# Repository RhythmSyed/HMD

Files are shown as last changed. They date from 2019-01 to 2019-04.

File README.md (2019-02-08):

# HMD
ECE 477 Team 6

HMD is a wearable Health Monitoring Device that provides the user with real-time health information through a continuous stream to the cloud and to a companion app for client-side use. The system includes a wide variety of sensors that allow the device to monitor the activity of the user through step tracking and monitoring sleep quality. To ensure uninterrupted wear, the battery level of the device is recorded to insure the device is always powered. The system also includes an alert system for sleep reminders, low battery levels, and alerts to family members in case of health concerns. The system will also incorporate a display attached to the wearable informing the user his total steps and the battery percentage of the device.

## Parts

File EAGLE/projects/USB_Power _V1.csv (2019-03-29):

Qty | Value | Device | Package | Parts | Description | BOM
2 |  | HEADER-1X2ROUND | 1X02_ROUND | JP1, JP2 | PIN HEADER
1 |  | SOLDERJUMPER | SOLDERJUMPER_ARROW_NOPASTE | SJ1 | SMD Solder JUMPER | EXCLUDE
1 |  | USB_MEDIUM | USB-MINI_MEDIUM | X1 | USB Connectors
1 | 10K\ | RESISTOR0805_NOOUTLINE | 0805-NO | R3 | Resistors
2 | 10µF | CAP_CERAMIC0805-NOOUTLINE | 0805-NO | C1, C2 | Ceramic Capacitors
1 | 2.5K | RESISTOR0805_NOOUTLINE | 0805-NO | R4 | Resistors
1 | JSTPH | JST_2PIN | JSTPH2 | CN2 | JST 2-Pin Right-Angle Connector
1 | MCP73831T-2ACI/OT | MCP73831/2 | SOT23-5 | U1 | MCP73831/2 LIPO Charger

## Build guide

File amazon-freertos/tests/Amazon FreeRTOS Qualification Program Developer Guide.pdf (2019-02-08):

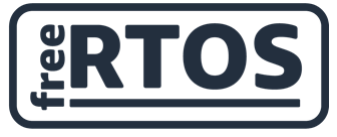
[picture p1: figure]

Copyright © 2018 Amazon Web Services, Inc. and/or its affiliates. All rights reserved.

# Amazon FreeRTOS Qualification Developer Guide

Document Version V1.1.3

Amazon FreeRTOS Qualification Developer Guide – V 1.1.3

Copyright © 2018 Amazon Web Services, Inc. and/or its affiliates. All rights reserved. | 2

## Amazon FreeRTOS Qualification: Developer Guide

Copyright © 2018 Amazon Web Services, Inc. and/or its affiliates. All rights reserved.

Amazon's trademarks and trade dress may not be used in connection with any product or service that is not Amazon's, in any manner that is likely to cause confusion among customers, or in any manner that disparages or discredits Amazon. All other trademarks not owned by Amazon are the property of their respective owners, who may or may not be affiliated with, connected to, or sponsored by Amazon.

Copyright © 2018 Amazon Web Services, Inc. and/or its affiliates. All rights reserved. | 3

# Revision History

Date | Versi on | Change History | Compatible Amazon FreeRTOS Version
July 31, 2018 | 1.0.0 | Initial Version. | 1.3.0
August 09, 2018 | 1.0.1 | Updates in appendices: • Updates in Porting Order chart. • Updates in PKCS#11 “Porting” section. • File path changes in TLS “Test Setup” section and TLS Server Setup step 9. • Fix hyperlinks in MQTT prerequisite section. • Add AWS CLI config instruction in BYOC certificate creation example. | 1.3.1 1.3.2
August 27, 2018 | 1.1.0 | Added tests for Over-the-air (OTA) updates and guidelines for bootloader | 1.4.0 1.4.1
October 08, 2018 | 1.1.1 | Added clarifications in (B3.1) tests enable constants table. Updated path changes of Unity module in “Create Test Project (B2.2)” section. Updates in appendices: • Updated Porting Order Flowchart. • Updated client credential certificate/key variable names in TLS “Test Setup” section. • Corrections of a file path in Secure Socket “Test Setup” section and TLS Server Setup. • Updated the path for echo servers in TLS “Test Setup” section and TLS Server Setup. | 1.4.2
November 07, 2018 | 1.1.2 | Updates in appendices: • Modifications of PKCS #11 PAL layer interface changes in PKCS #11 porting section. • Updated GSG template, “Download and Configure Amazon FreeRTOS” section. • Updated the path of CertificateConfigurator.html. | 1.4.3 1.4.4
November 26, 2018 | 1.1.3 | Added BLE section. Updated with IoT Device Tester information. Added cmake preparation section. | To be assigned

Copyright © 2018 Amazon Web Services, Inc. and/or its affiliates. All rights reserved. | 4

# Contents

Copyright © 2018 Amazon Web Services, Inc. and/or its affiliates. All rights reserved. | 5
5.15 | Appendix O: Checklist for Qualification | 67
5.16 | Appendix P: Troubleshooting Porting Setup | 68
5.17 | Appendix Q: Instructions to Create a BYOC (ECDSA) | 69
5.18 | Appendix R: Source for ca.config | 71
5.19 | Appendix S: Modify issuer in a certificate | 77
5.20 | Appendix T: Getting Started Guide Template | 81
5.21 | Appendix U: Hardware Information | 83
5.22 | Appendix V: Information for listing on the Amazon FreeRTOS Console | 85
5.23 | Appendix W: Glossary | 86

Copyright © 2018 Amazon Web Services, Inc. and/or its affiliates. All rights reserved. | 6

# 1 Introduction

## 1.1 What is the Amazon FreeRTOS Qualification?

The Amazon FreeRTOS Qualification (AFQ) defines a process that the author of an Amazon FreeRTOS port¹ must follow, and a set of tests that the port must pass, in order for the port to be described as 'qualified by Amazon'. Amazon only distributes and supports Amazon FreeRTOS ports that have passed the qualification program. The purpose of the AFQ is to give developers confidence that qualified Amazon FreeRTOS ports behave correctly and consistently with each other.

AWS provides a free test automation framework called AWS IoT Device Tester for Amazon FreeRTOS, which developers can use to automate running of the qualification tests. See https://aws.amazon.com/freertos/device-tester for more information on how to set it up.

## 1.2 Target System Requirements

It is recommended that Amazon FreeRTOS is only qualified on microcontrollers (MCUs) that have a minimum processing speed of 25MHz, a minimum of 64K bytes of RAM, and a minimum of 128K bytes of program memory per executable image stored on the MCU. For future qualification requirement with Over-the-air update (OTA) functionality, two executable images must be stored in program memory at the same time.

## 1.3 Document Outline

This document guides you through setting up your Amazon FreeRTOS project, porting Amazon FreeRTOS libraries, building and testing your ports using the Amazon FreeRTOS Qualification tests. Appendixes provide more detail information on each Amazon FreeRTOS library.

We also prepared a checklist for the process: Appendix O: Checklist for Qualification

1 An Amazon FreeRTOS port is a board-specific implementation of APIs for certain Amazon FreeRTOS libraries. The port enables these APIs to work on the specific board, and implements the required integration with device drivers and BSPs provided by the platform vendor. It should also include any configuration adjustments (e.g. clock rate, stack size, heap size etc.) required by the board.

Copyright © 2018 Amazon Web Services, Inc. and/or its affiliates. All rights reserved. | 7

# 2 Amazon FreeRTOS Qualification Test Project

Follow the steps below.

## 2.1 Download Amazon FreeRTOS Source Code

You can download the Amazon FreeRTOS source code and test code from GitHub:

https://github.com/aws/amazon-freertos

Please download the latest release code from the “release” branch. You should import the repository to your own private GitHub repository and configure to watch Amazon FreeRTOS public repository. You will get notifications if there are new releases on our release branch.

If you are using Windows, you must keep the file path short (for example clone to C:\AFreeRTOS rather than C:\Users\username\programs\projects\AmazonFreeRTOS\) to avoid a Windows limitation with long file paths. The chosen folder will be referred as $AFR_HOME from here on in the document.

## 2.2 Set Up Your Amazon FreeRTOS Project

At the end of this step, you will have a working project that can write to a serial console.

### 2.2.1 Preparing Amazon FreeRTOS Folders

All qualified Amazon FreeRTOS ports use the same directory structure. New files, including IDE project files, must be created in the correct folder locations.

The directory structure is explained below. Detailed instructions on how to create the same directory structure are listed in the grey box.

Directory Structure:

The three root level folders under $AFR_HOME are:

$AFR_HOME
├───demos | Contains projects that build demo applications
├───lib | Contains Amazon FreeRTOS and third-party libraries
└───tests | Contains projects that build qualification tests

Create your project in the tests folder, which is structured as follows:

$AFR_HOME
└───tests
├───common | Contains files built by all test projects
├───pc | Contains a reference test project for the FreeRTOS Windows port
└───vendor | Template, to be renamed to the name of the MCU vendor
└───board | Template, to be renamed to the name of the development board

Copyright © 2018 Amazon Web Services, Inc. and/or its affiliates. All rights reserved. | 8

Instructions:

1. Rename the $AFR_HOME/tests/vendor folder to the name of the company that manufactures the MCU – from here on the folder is referred to as [vendor].
2. Rename the $AFR_HOME/tests/board folder to the name of the development board being qualified – from here on the folder is referred to as [board].

The $AFR_HOME/tests/[vendor]/[board] folder is a template provided to simplify the creation of a new test project and ensures all test projects have a consistent organization. It has the following structure:

$AFR_HOME
└───tests
└───[vendor]
└───[board]
├───common
│ | ├───application_code | Contains main.c, which itself contains main()
│ | │ | └───vendor_code | Contains vendor supplied board specific files
│ | └───config_files | Contains Amazon FreeRTOS config files
└───ide | Contains an IDE specific project

Test projects always require vendor-supplied driver libraries. Some vendor-supplied libraries, such as a header file that maps a GPIO output to an LED output, are specific to the target development board. Other vendor-supplied libraries, such as the GPIO library itself, are specific to the target MCU family.

For Vendor-supplied driver libraries that are specific to the target development board:

Instructions (continued):

3. Save any required vendor-supplied libraries that are specific to the board in the $AFR_HOME/tests/[vendor]/[board]/common/application_code/vendor_code folder.
4. Rename the $AFR_HOME/tests/[vendor]/[board]/ide folder to the name of the IDE that will be used to build the test project – from here on the folder is referenced as [IDE].

Vendor-supplied driver libraries that are specific to the target MCU family belong in the $AFR_HOME/lib/third_party/mcu_vendor folder, which has the following structure:

$AFR_HOME
└─lib
├──AmazonLib1 | Contains an Amazon FreeRTOS library (example name only)
├──AmazonLib2 | Contains an Amazon FreeRTOS library (example name only)
└──third_party | Contains all non-board specific third-party libraries
├───Lib1 | Contains a third-party library (example name only)
├───Lib2 | Contains a third-party library (example name only)
└───mcu_vendor Contains vendor-supplied MCU specific libraries └──vendor Template, to be renamed to the name of the MCU vendor └─driver_library Template, to be renamed to the library name └─driver_library_version Template, to be renamed to the library version

Copyright © 2018 Amazon Web Services, Inc. and/or its affiliates. All rights reserved. | 9

Instructions (continued):

5. Rename the $AFR_HOME/lib/third_party/mcu_vendor/vendor folder to [vendor] (the name of the company that manufactures the MCU).
6. Likewise, rename the contained driver_library folder to the name of the vendor’s MCU specific driver library, and the contained driver_library_version folder to the version number of the vendor’s MCU specific driver library.
7. Copy the vendor-supplied driver library into the newly renamed driver_library_version folder.

NOTE: DO NOT save vendor-supplied libraries that are specific to the MCU family anywhere within either the $AFR_HOME/tests or $AFR_HOME/demos folders!

### 2.2.2 Create the Test Project

All qualified Amazon FreeRTOS test projects look the same when viewed from within an IDE. This section describes and demonstrates the required project structure. By the end of this section you will have a project with FreeRTOS Kernel libraries ready to run. The next section (2.32.3) will cover porting of other Amazon FreeRTOS libraries into the project.

Instructions:

1. Read this section of the document, and then replicate the project it describes, but using the selected IDE, and targeting the hardware being qualified. Take care to ensure the structure of the created project matches that described below.

NOTE 1: All files in the project must be built in the file’s original position within the folder structure. They are imported into the project by linking the files. Never directly copy files into the project’s folder or use absolute file paths.

NOTE 2: If you are using an Eclipse based IDE, do not configure the project to build all the files in any given folder. Instead, add source files into the project by linking to each source file individually.

The project is called aws_tests. Under aws_tests, there are three virtual folders. In this context, a virtual folder is created in an IDE to better organize the source code. It may not correspond to a physical directory on disk. The three virtual folders are application_code, config_files and lib, as described below:

aws_tests | The project name
├───application_code | Contains application logic, in this case it is AFQ test code
├───config_files | Contains header files that configure Amazon FreeRTOS libraries
└───lib | Contains Amazon and third-party libraries

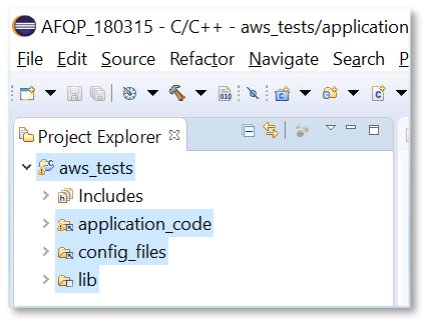
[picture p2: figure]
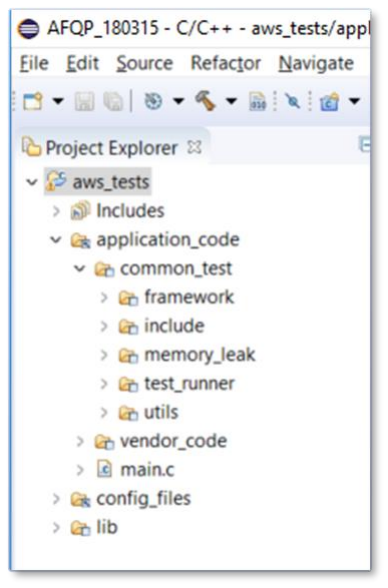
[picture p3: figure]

Copyright © 2018 Amazon Web Services, Inc. and/or its affiliates. All rights reserved. | 10

Error! Reference source not found. shows how the top three virtual folders appear in an IDE. The depicted IDE is Eclipse, but the structure is the same in all IDEs.

Figure 1 The top three virtual folders viewed in an IDE’s project explorer view

Figure 2 shows the contents of the application_code virtual folder.

Figure 2 An IDE project with the application_code virtual folder expanded

NOTE:

- The main.c file, and the vendor_code folder, are (physically on the disk) located in the $AFR_HOME/tests/[vendor]/[board]/common/ application_code folder.
- common_test is a virtual folder – it does not actually exist within the $AFR_HOME directory structure. The folders under common_test are located in the $AFR_HOME/tests/common folder. The project builds the source files located in those folders.

NOTE:

- The “Includes” folder is generated automatically by Eclipse. It is not part of the required structure

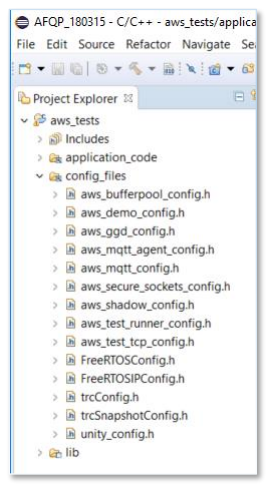
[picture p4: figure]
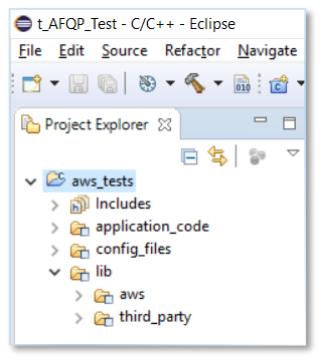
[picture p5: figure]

Copyright © 2018 Amazon Web Services, Inc. and/or its affiliates. All rights reserved. | 11

Figure 3 shows the contents of the config_files virtual folder.

Figure 3 An IDE project with the config_files folder expanded

Figure 4 shows the contents of the lib virtual folder.

Figure 4 IDE project with the lib group expanded

NOTE:

- The files shown under config_files are located in the
$AFR_HOME/tests/[vendor]/[board]/common /config_files folder.

NOTE:

- aws and third_party are virtual folders.

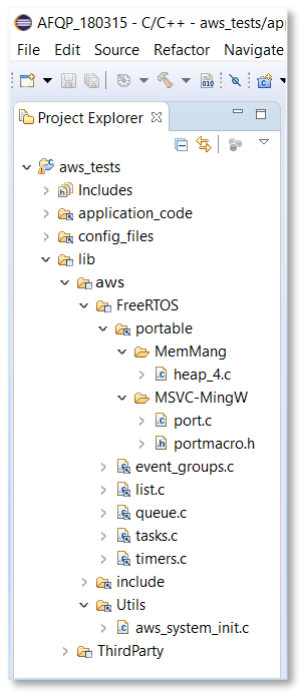
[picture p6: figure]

Copyright © 2018 Amazon Web Services, Inc. and/or its affiliates. All rights reserved. | 12

Figure 5 shows the contents of the lib/aws folder, which contains AWS (as opposed to third party) provided libraries. It only contains FreeRTOS kernel library at this stage. You will import more libraries in this folder during later porting effort.

Figure 5 IDE project with the lib/AWS group expanded

NOTE:

- The files and folders shown under lib/aws/FreeRTOS are located in the $AFR_HOME/lib/FreeRTOS folder. The figure shows lib/aws/FreeRTOS/portable/MSVC-MingW being included in the project. That folder contains the FreeRTOS kernel Windows port and should be substituted with whichever folder contains the correct FreeRTOS port for your target IDE and MCU, see below instruction.
- The file shown under
lib/aws/FreeRTOS/portable/MemMang is located in the $AFR_HOME/lib/FreeRTOS/MemMang folder. It is FreeRTOS memory management implementation.
- The files shown under lib/aws/include are located in the $AFR_HOME/lib/include folder. Although not shown in Figure , it includes all the header files and folders under $AFR_HOME/lib/include.
- aws_system_init.c is located in the $AFR_HOME/lib/utils folder.

Instructions (continued):

1. Replicate the folder structure (continued)
a. Import the FreeRTOS Kernel port for your compiler and architecture in place of lib/aws/FreeRTOS/portable/MSVC_MingW in Figure 5. $AFR_HOME/lib/FreeRTOS/portable contains the FreeRTOS kernel port files organized first by compiler, and then by architecture.
b. Import one of the FreeRTOS Kernel memory management implementation to lib/aws/FreeRTOS/portable/MemMang. For Amazon FreeRTOS, we use heap_4.c. For more information, please visit FreeRTOS Memory Management (https://www.freertos.org/a00111.html)

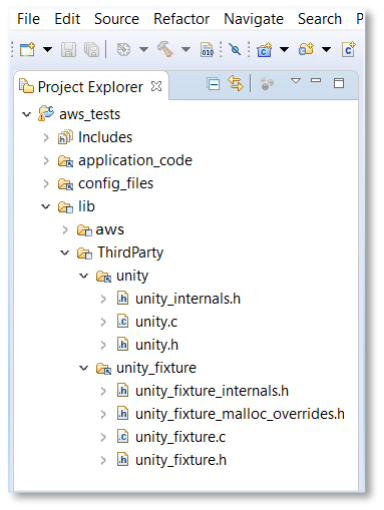
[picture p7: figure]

Copyright © 2018 Amazon Web Services, Inc. and/or its affiliates. All rights reserved. | 13

Figure 6 shows the contents of the lib/third_party directory.

Figure 6 IDE project with the lib/third_party group expanded

Instructions (continued, to be followed after creating the project):

2. Make sure the following compiler include paths are set in the project property.
a. $AFR_HOME/tests/common/include, which is aws_tests/application_code/common_tests/include when viewed in the IDE project.
b. $AFR_HOME/lib/include, which is aws_tests/lib/aws/include when viewed in the IDE.
c. $AFR_HOME/lib/include/private, which is aws_tests/lib/aws/include/private when viewed in the IDE.
d. $AFR_HOME/lib/FreeRTOS/portable/[compiler]/[architecture], which is aws_tests/lib/aws/FreeRTOS/portable/[compiler]/[architecture] when viewed in the IDE.
e. $AFR_HOME/lib/third_party/unity/src, which is aws_tests/lib/third_party/unity when viewed in the IDE.
f. $AFR_HOME/lib/third_party/unity/extras/fixture/src, which is aws_tests/lib/third_party/unity_fixture when viewed in the IDE.
g. $AFR_HOME/demos/vendor/board/common/config_files, which is aws_tests/config_files when viewed in the IDE.
h. Any paths necessitated by vendor-supplied driver libraries.
3. Define the following two project level macros in your IDE:
- UNITY_INCLUDE_CONFIG_H
- AMAZON_FREERTOS_ENABLE_UNIT_TESTS

NOTE:

- unity and unity_fixture are virtual folders.
- The files shown under unity are located in the $AFR_HOME/lib/third_party/unity/src folder.
- The files shown under unity_fixture are located in the $AFR_HOME/lib/third_party/unity/extras/fixture folder.
- Although not shown in Figure , also add the MCU specific vendor-supplied driver libraries that were saved in the
$AFR_HOME/lib/third_party/[mcu_vendor]/[vendor]/ [driver_library]/[driver_library_version] folder (see section Preparing Amazon FreeRTOS Folders).

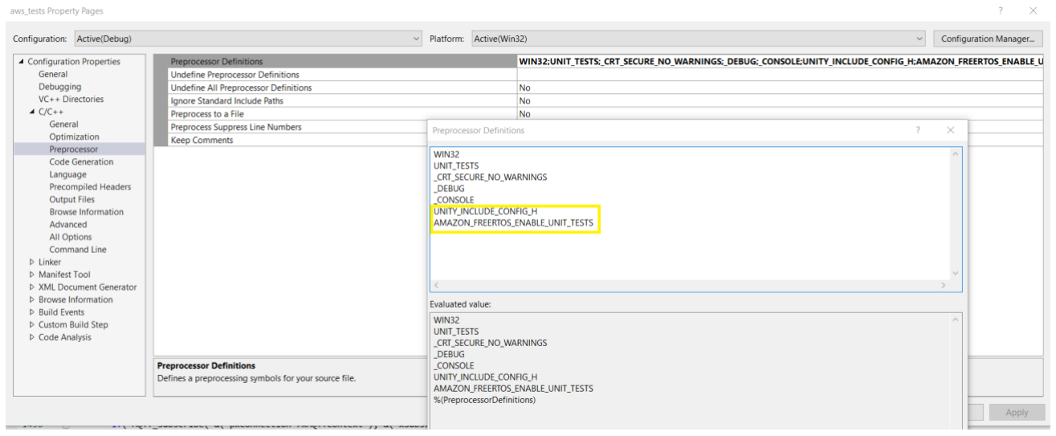
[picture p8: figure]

Copyright © 2018 Amazon Web Services, Inc. and/or its affiliates. All rights reserved. | 14

Figure 7 Preprocessor Macro Definitions Example (Visual Studio)

Visual Studio 2017 Example: Project Properties => Preprocessor => Preprocessor Definitions

4. Implement configPRINT_STRING() as described in Appendix A.
5. Make sure the new project builds successfully, that the resultant executable binary can be loaded to the target hardware. If you run the project in debug mode, the pc should stop at the first line of
main().

Copyright © 2018 Amazon Web Services, Inc. and/or its affiliates. All rights reserved. | 15

## 2.3 Port, Build and Test Libraries and Demos

### 2.3.1 Port Libraries, Build and Test Libraries

With the folder structure and test projects prepared you are ready to start porting and testing the Amazon FreeRTOS libraries. You must enable AFQ test group first.

$AFR_HOME/tests/[vendor]/[board]/common/config_files/aws_test_runner_config.h contains a macro defined shown below. Uncomment the following line:

/*#define testrunnerAFQP_ENABLED */

Then bring an Amazon FreeRTOS library into your test project and port the library to your hardware. The libraries are listed in below table. The detailed instruction on porting and testing procedures are listed in the appendices – one appendix per library. The order of the appendices accounts for interdependencies between libraries so should be followed in turn.

Library | Details in Location | Notes
configPRINT_STRING Macro | Appendix A | Required for console output.
FreeRTOS Kernel | Appendix B | Required for the FreeRTOS kernel.
Wi-Fi Management | Appendix C | Required only if hardware supports network connectivity over Wi-Fi.
FreeRTOS TCP/IP Stack | Appendix D | Required only if a board does not have its own TCPIP stack support.
Secure Sockets | Appendix E | Required for AWS cloud connectivity.
PKCS#11 | Appendix F | Required for over-the-air (OTA) and TLS support.
TLS | Appendix G | Required for TLS support.
MQTT | Appendix H | Required for AWS cloud connectivity.
OTA Updates | Appendix I | Required for OTA updates.
Bootloader (demo) | Appendix J | Required for OTA updates.
Bluetooth Low Energy (Beta) | Appendix K | Required for Bluetooth Low Energy (BLE) support

Copyright © 2018 Amazon Web Services, Inc. and/or its affiliates. All rights reserved. | 16

There are constants defined in $AFR_HOME/tests/[vendor]/[board]/common/config_files/aws_test_runner_config.h file which can be used as a switch to trigger a test set for a library. To enable a set of tests, set the constant to 1. These constants listed in table below:

Defined constant to trigger a set of tests on a library | Default value. (set to ‘1’ for enabling the test) | Required for AFQ
testrunnerFULL_CBOR_ENABLED | 0
testrunnerFULL_OTA_AGENT_ENABLED | 0 | Y (if supports OTA)
testrunnerFULL_OTA_PAL_ENABLED | 0 | Y (if supports OTA)
testrunnerFULL_MQTT_ALPN_ENABLED | 0
testrunnerFULL_MQTT_STRESS_TEST_ENABLED | 0
testrunnerFULL_MQTT_AGENT_ENABLED | 0
testrunnerFULL_TCP_ENABLED | 0 | Y
testrunnerFULL_GGD_ENABLED | 0
testrunnerFULL_GGD_HELPER_ENABLED | 0
testrunnerFULL_SHADOW_ENABLED | 0
testrunnerFULL_MQTT_ENABLED | 0 | Y
testrunnerFULL_PKCS11_ENABLED | 0 | Y
testrunnerFULL_CRYPTO_ENABLED | 0
testrunnerFULL_TLS_ENABLED | 0 | Y
testrunnerFULL_WIFI_ENABLED | 0 | Y
testrunnerFULL_BLE_ENABLED | 0 | Y (if supports BLE)

This is a vendor configurable file. If your board does not support a certain feature (i.e. OTA), you can define the corresponding test sets to not supported, like the following:

#define testrunnerFULL_OTA_AGENT_ENABLED testrunnerUNSUPPORTED

NOTE: If you have setup AWS IoT Device Tester for Amazon FreeRTOS, to run the test project you do not need to modify this file.

### 2.3.2 “Hello World” Demo and Getting Started Guide

Prepare the “Hello World” demo project in the code packaged delivered to Amazon. The project creation process is similar to the test project creation. Please see Appendix N: “Hello World” Demo Project Set Up for detailed instructions.

Prepare a “Getting Started Guide” for your board to help users run the Hello World Demo project (and any other demos you may include). You can use the Getting Started Guide template to start and look at the guide for the Window Simulator (https://docs.aws.amazon.com/freertos/latest/userguide/getting_started_windows.html) for reference.

Copyright © 2018 Amazon Web Services, Inc. and/or its affiliates. All rights reserved. | 17

### 2.3.3 Configure your board name

Please put your board name in: $AFR_HOME/demos/[vendor]/[board]/common/config_files/FreeRTOSConfig.h

#define mqttconfigMETRIC_PLATFORM "Platform=Unknown"

Replace “Unknown” with your own board name.

Copyright © 2018 Amazon Web Services, Inc. and/or its affiliates. All rights reserved. | 18

# 3 FAQs

### 1. What is an Amazon FreeRTOS port?

An Amazon FreeRTOS port is a board-specific implementation of APIs for certain Amazon FreeRTOS libraries. The port enables these APIs to work on the specific board, and implements the required integration with device drivers and BSPs provided by the platform vendor. It should also include any configuration adjustments (e.g. clock rate, stack size, heap size) required by the board.

### 2. Do I need to retest for minor version releases of Amazon FreeRTOS?

There is no need to retest for qualification with minor version releases of Amazon FreeRTOS.

### 3. What network ports will need to be opened to run AFQ tests?

The network connections needed in the AFQ tests include
Port | Protocol
443, 8883 | MQTT
8443 | Greengrass Discovery

Copyright © 2018 Amazon Web Services, Inc. and/or its affiliates. All rights reserved. | 19

# 4 Contact Us

If you have any questions, please post questions to AWS Amazon FreeRTOS forum (you must have an AWS account): http://forums.aws.amazon.com.

You can also post questions in GitHub/issues board (you must have a GitHub account): https://github.com/aws/amazon-freertos/issues.

# 5 Appendix

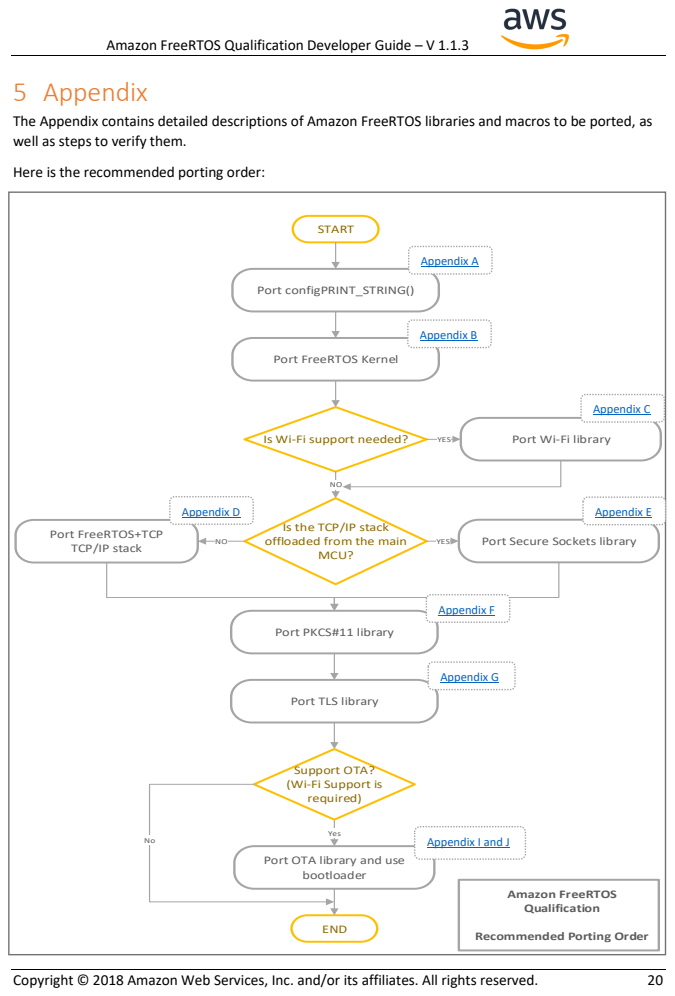
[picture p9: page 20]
Copyright © 2018 Amazon Web Services, Inc. and/or its affiliates. All rights reserved.; Port configPRINT_STRING(); START; Is Wi-Fi support needed?; Port Wi-Fi library; MCU?; END; YES; Amazon FreeRTOS Qualification; bootloader; Yes; Appendix A; Appendix B; Appendix C; Appendix D; Appendix E; Appendix F; Appendix G; Appendix I and J

The Appendix contains detailed descriptions of Amazon FreeRTOS libraries and macros to be ported, as
well as steps to verify them.

Here is the recommended porting order:

Port FreeRTOS Kernel

Port Secure Sockets library Port FreeRTOS+TCP
TCP/IP stack

Is the TCP/IP stack
offloaded from the main

Port PKCS#11 library

Port TLS library

Support OTA?
(Wi-Fi Support is
required)

Port OTA library and use

Recommended Porting Order

Copyright © 2018 Amazon Web Services, Inc. and/or its affiliates. All rights reserved. | 21

## 5.1 Appendix A: configPRINT_STRING()

### Description

configPRINT_STRING() is a macro used by the AFQ test framework to output test results as human readable ASCII strings. It must be implemented before AFQ porting and testing can begin.
These instructions assume test results are output over a UART serial port.

### Pre-requisites

1. A development board that supports UART or virtual COM port output.
2. A test project that was created in accordance with the instructions provided in the body of this document, and that is building vendor-supplied UART initialization and output functions.
3. The UART initialization and output must not have any dependency on FreeRTOS.

### Setup

1. Connect a terminal emulator, such as TeraTerm, to the port on the target hardware that is to be used to output test results.

### Porting

1. Locate the call to configPRINT_STRING( “Test Message” ) within the function prvMiscInitialization(), which is itself in the file
$AFR_HOME/tests/[vendor]/[board]/common/application_code/main.c.
2. Immediately before the call to configPRINT_STRING( “Test Message” ), add code that uses the vendor-supplied UART driver to initialize the UART to 115200 baud
3. $AFR_HOME/tests/[vendor]/[board]/common/config_files/FreeRTOSConfig.h contains an empty definition of configPRINT_STRING(). The macro takes a NULL terminated ASCII C string as its only parameter. Update the empty definition of configPRINT_STRING() so that it calls the vendor-supplied UART output function. For example, if the UART output function has the following prototype:

then you would implement configPRINT_STRING() as:

### Manual Testing

Build and execute the application. If “Test Message” appears in the UART console then the console is connected and configured correctly, and configPRINT_STRING() is behaving as expected. If this is the void MyUARTOutput( char *DataToOutput, size_t LengthToOutput );

#define configPRINT_STRING( X ) MyUARTOutput( (X), strlen( (X) ) )

Copyright © 2018 Amazon Web Services, Inc. and/or its affiliates. All rights reserved. | 22

case then configPRINT_STRING() testing is complete and the call to configPRINT_STRING( “Test Message” ) can be removed from prvMiscInitialization().

Copyright © 2018 Amazon Web Services, Inc. and/or its affiliates. All rights reserved. | 23

## 5.2 Appendix B: FreeRTOS kernel

### Description

Amazon FreeRTOS uses the FreeRTOS kernel for multitasking and inter-task communications. This appendix describes how to integrate a port of the FreeRTOS kernel into the AFQ test project.

The FreeRTOS.org website contains a list of all the available kernel ports. (https://freertos.org/RTOS_ports.html)

Porting the FreeRTOS kernel to a new architecture is out of scope of this document. Contact the Amazon FreeRTOS Qualification team if a port does not exist for your architecture.

### Pre-requisites

1. An official FreeRTOS kernel port for the target MCU architecture.
2. A test project that was created in accordance with the instructions provided in the body of this document (Create the Test Project), and that includes the correct FreeRTOS kernel port files for the MCU and compiler in use.
3. An implementation of configPRINT_STRING() that was created and tested as described in Appendix A.

### Porting

The header file $AFR_HOME/tests/[vendor]/[board]/common/config_files/FreeRTOSConfig.h contains application specific FreeRTOS kernel configuration settings. The FreeRTOS.org website provides a description of each configuration option. (https://freertos.org/a00110.html) In particular, ensure the following constants are set correctly for your hardware:

Configuration definitions | Comment
configCPU_CLOCK_HZ | The frequency of the clock used to generate the tick interrupt.
configMINIMAL_STACK_SIZE | As a starting point, this can be set to whichever value is used in the official FreeRTOS demo for the FreeRTOS kernel port in use. Official FreeRTOS demos are those distributed from the FreeRTOS.org web site. Ensure stacks overflow (https://www.freertos.org/Stacks-and-stack-overflow-checking.html) checking is set to 2, and increase configMINIMAL_STACK_SIZE if overflows occur. To save RAM, set stack sizes to the minimum value that does not result in a stack overflow.
configTOTAL_HEAP_SIZE | Sets the size of the FreeRTOS heap. (https://www.freertos.org/a00111.html) Like task stack sizes, the heap size can be tuned to ensure unused heap space does not consume RAM.

ARM Cortex-M3, M4 and M7 devices must also have configPRIO_BITS and configMAX_SYSCALL_INTERRUPT_PRIORITY (https://www.freertos.org/RTOS-Cortex-M3-M4.html) set correctly.

Copyright © 2018 Amazon Web Services, Inc. and/or its affiliates. All rights reserved. | 24

The MQTT (Appendix H) and Secure Sockets (Appendix E) libraries have not been ported yet, so it is necessary to comment out the lines that call BUFFERPOOL_Init(), MQTT_AGENT_Init() and SOCKETS_Init() from within function SYSTEM_Init(), which is implemented in $AFR_HOME/lib/utils/aws_system_init.c.

### Test Setup

No further setup is required for this section.

### Test Execution

1. Build and execute the project.
2. If a “.” appears in the UART console every 5 seconds then the FreeRTOS kernel is operating as expected and this test is complete. Set configUSE_IDLE_HOOK to 0 in $AFR_HOME/tests/[vendor]/[board]/common/config_files/FreeRTOSConfig.h before moving to the next section. Setting configUSE_IDLE_HOOK to 0 stops the FreeRTOS kernel from executing vApplicationIdleHook(), and so stop the “.” Being output during future test executions.
3. If a “.” appears at any other frequency then check the setting of configCPU_CLOCK_HZ in $AFR_HOME/tests/[vendor]/[board]/common/config_files/FreeRTOSConfig.h. configCPU_CLOCK_HZ must be set to the correct value for your board.

Copyright © 2018 Amazon Web Services, Inc. and/or its affiliates. All rights reserved. | 25

## 5.3 Appendix C: Wi-Fi Management

### Description

The Wi-Fi Management library is the Amazon FreeRTOS interface to vendor-supplied Wi-Fi drivers. Skip this section if your hardware does not support Wi-Fi.

### Pre-requisites

1. A test project that was created in accordance with the instructions provided in the body of this document, and that is building vendor-supplied Wi-Fi drivers.
2. An implementation of configPRINT_STRING() that was created and tested as described in Appendix A.
3. A validated FreeRTOS kernel configuration, as described in Appendix B: FreeRTOS kernel
4. Two wireless Access Points.

### Preparing the IDE Project

1. Add the source file $AFR_HOME/lib/wifi/portable/[vendor]/[board]/aws_wifi.c into the [project_top_level]/lib/aws/wifi virtual folder of the IDE project.
2. Add the source file $AFR_HOME/tests/common/wifi/aws_test_wifi.c into the [project_top_level]/application_code/common_tests/wifi virtual folder of the IDE project.
3. Enable the Wi-Fi connection code in $AFR_HOME/tests/[vendor]/[board]/common/application_code/main.c by deleting the #if 0 and #endif compiler directives in the functions vApplicationDaemonTaskStartupHook(void) and prvWifiConnect(void).

### Porting

1. $AFR_HOME/lib/wifi/portable/[vendor]/[board]/aws_wifi.c contains empty definitions of a set of Wi-Fi management functions. Use the vendor-supplied Wi-Fi driver library to implement at least the subset of functions listed in the table below. $AFR_HOME/lib/include/aws_wifi.h provides the information necessary to complete the implementations.
Function | Description
WIFI_On | Turns on Wi-Fi module. Initializes the drivers
WIFI_ConnectAP | Connects to a Wi-Fi Access Point (AP)
WIFI_Disconnect | Disconnects from the currently connected AP
WIFI_Scan | Performs a Wi-Fi network scan
WIFI_GetIP | Retrieves the Wi-Fi interface’s IP address
WIFI_GetMAC | Retrieves the Wi-Fi interface’s MAC address
WIFI_GetHostIP | Retrieves the host IP address from a hostname using DNS

Copyright © 2018 Amazon Web Services, Inc. and/or its affiliates. All rights reserved. | 26

Since the MQTT library is not used for running Wi-Fi tests, comment out the lines that call BUFFERPOOL_Init(), MQTT_AGENT_Init()in function SYSTEM_Init()in file $AFR_HOME/lib/utils/aws_system_init.c. Bufferpool and mqtt_agent are used in MQTT library. If you have not ported the SOCKETS library (Appendix E), comment out the line that calls SOCKETS_Init()in function SYSTEM_Init(), in file $AFR_HOME/lib/utils/aws_system_init.c.

### Test Setup

If you use AWS IoT Device Tester for Amazon FreeRTOS to run tests you don’t need to perform the following setup steps. See https://aws.amazon.com/freertos/device-tester for more information.

1. In $AFR_HOME/tests/common/include/aws_clientcredential.h, set the macros shown in table below to be correct for the first Wi-Fi access point.
Macro name | Value
clientcredentialWIFI_SSID | The Wi-Fi SSID as a C string (in quotes)
clientcredentialWIFI_PASSWORD | The Wi-Fi password as a C string
clientcredentialWIFI_SECURITY | Either eWiFiSecurityOpen, eWiFiSecurityWEP, eWiFiSecurityWPA, or eWiFiSecurityWPA2. eWiFiSecurityWPA2 is recommended.
2. In $AFR_HOME/tests/common/wifi/aws_test_wifi.c, set the macros shown in table below to be correct for the second Wi-Fi access point.
Macro name | Value
testwifiWIFI_SSID | The Wi-Fi SSID as a C string (in quotes)
testwifiWIFI_PASSWORD | The Wi-Fi password as a C string
testwifiWIFI_SECURITY | Either eWiFiSecurityOpen, eWiFiSecurityWEP, eWiFiSecurityWPA, or eWiFiSecurityWPA2. eWiFiSecurityWPA2 is recommended.

The Wi-Fi management tests listed in the bullet points below have a dependency on the Secure Sockets library, which may not have been ported yet. If the Secure Sockets library has not been ported then all the Wi-Fi management tests other than those listed in the bullets below must pass. After the Secure Sockets library has been ported it is necessary to re-run the Wi-Fi management tests to ensure all the tests (including those in the bullet points below) pass. Additionally, the tests listed in the bullet points attempt to communicate with an echo server. See the Appendix E: Secure Sockets section “Test Setup” for information on starting the echo server.

- WiFiConnectionLoop
- WiFiIsConnected

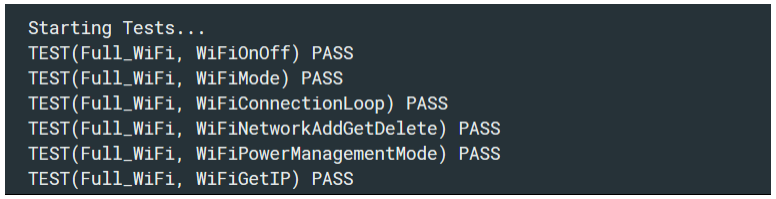
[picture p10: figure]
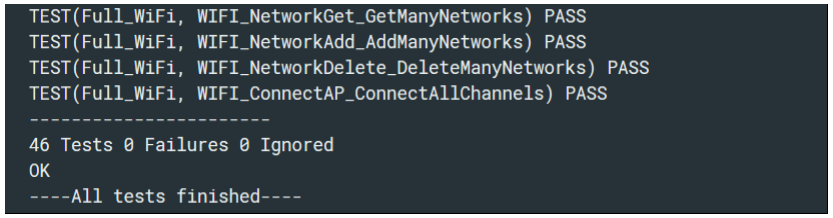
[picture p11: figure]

Copyright © 2018 Amazon Web Services, Inc. and/or its affiliates. All rights reserved. | 27
- WiFiConnectMultipleAP
- WiFiSeperateTasksConnectingAndDisconnectingAtOnce
3. Enable the Wi-Fi tests, by setting the testrunnerFULL_WIFI_ENABLED macro in $AFR_HOME/tests/[vendor]/[board]/common/config_files/aws_test_runner_config.h to 1.

### Test Execution

1. Build and execute the test project.
2. View the test results in the UART console. As noted in the ‘Test Setup’ section of this appendix, not all the tests will pass until porting of the Secure Sockets library is complete. If all the tests that are expected to pass are passing, then save the test results by cutting and pasting them from the UART console into a text file, and move to the next section.
Example output:

…

Alternatively, you can use AWS IoT Device Tester for Amazon FreeRTOS to test your implementation of WiFi.

Copyright © 2018 Amazon Web Services, Inc. and/or its affiliates. All rights reserved. | 28

## 5.4 Appendix D: FreeRTOS TCP/IP Stack

### Description

FreeRTOS+TCP is the TCP/IP stack used by Amazon FreeRTOS. See https://www.freertos.org/FreeRTOS-Plus/FreeRTOS_Plus_TCP (https://www.freertos.org/FreeRTOS-Plus/FreeRTOS_Plus_TCP) for more information. Skip this section if your target hardware offloads TCP/IP functionality to a separate network processor or module.

This appendix only describes how to create a port to the target hardware’s Ethernet driver, and test as far as ensuring the Ethernet driver can connect to the network. Actually sending and receiving data is not tested until the Secure Sockets library port is complete.

### Pre-requisites

1. A test project that was created in accordance with the instructions provided in the body of this document, and that is building vendor-supplied Ethernet drivers.
2. An implementation of configPRINT_STRING() that was created and tested as described in Appendix A.
3. A validated FreeRTOS kernel configuration, as described in Appendix B: FreeRTOS kernel.

### Preparing the IDE Project

In all steps below, add source files to the IDE project from their existing location on the disk (by reference) – do not create duplicate copies of source files on the disk:

1. Add the source files from the $AFR_HOME/lib/FreeRTOS-Plus-TCP/source directory to the [project_top_level]/lib/FreeRTOS-Plus-TCP/source folder of the IDE project.
2. Add the header files from the $AFR_HOME/lib/FreeRTOS-Plus-TCP/include directory to the [project_top_level]/lib/FreeRTOS-Plus-TCP/include folder of the IDE project.
3. Add the port source files from the $AFR_HOME/lib/FreeRTOS-Plus-TCP/source/portable/NetworkInterface/[board_family]/ directory to the [project_top_level]/lib/FreeRTOS-Plus-TCP/portable/NetworkInterface folder of the IDE project.
4. Add the $AFR_HOME/lib/FreeRTOS-Plus-TCP/source/portable/BufferManagement/BufferAllocation_2.c source file to the [project_top_level]/lib/FreeRTOS-Plus-TCP/portable/BufferManagement folder of the IDE project.

FreeRTOS has five example heap implementations under $AFR_HOME /lib/FreeRTOS/portable/MemMang. Using FreeRTOS+TCP and BufferAllocation_2.c requires the heap_4.c implementation.

5. Add the directory $AFR_HOME/lib/FreeRTOS-Plus-TCP/include to your compiler’s include path.

Copyright © 2018 Amazon Web Services, Inc. and/or its affiliates. All rights reserved. | 29

### Porting

1. Check the $AFR_HOME/lib/FreeRTOS-Plus-TCP/source/portable/NetworkInterface/ directory to see if a port to your target hardware already exists.
2. If a port does not exist, then:
a. Rename the $AFR_HOME/lib/FreeRTOS-Plus-TCP/source/portable/NetworkInterface/[board_family] directory to be appropriate for the target hardware.
b. Follow the instruction on the FreeRTOS.org website for porting the TCP/IP stack to a different microcontroller, (https://www.freertos.org/FreeRTOS-Plus/FreeRTOS_Plus_TCP/Embedded_Ethernet_Porting.html) and if necessary, a different compiler, (https://www.freertos.org/FreeRTOS-Plus/FreeRTOS_Plus_TCP/Embedded_Compiler_Porting.html) to create a new port that uses the vendor supplied Ethernet drivers. Implement the new port in a file called NetworkInterface.c, and save the file in the newly renamed directory.
Note: The files in $AFR_HOME/lib/FreeRTOS-Plus-TCP/source/portable/BufferManagement are used by multiple ports so must not be edited.
3. Update the FreeRTOS+TCP configuration file $AFR_HOME/tests/[vendor/[board]/common/config_files/FreeRTOSIPConfig.h so it is correct for your target hardware. The FreeRTOS.org website describes each configuration option. (https://www.freertos.org/FreeRTOS-Plus/FreeRTOS_Plus_TCP/TCP_IP_Configuration.html)

Since the MQTT library is not used for running Wi-Fi tests, comment out the lines that call BUFFERPOOL_Init(), MQTT_AGENT_Init()in function SYSTEM_Init()in file $AFR_HOME/lib/utils/aws_system_init.c. Bufferpool and mqtt_agent are used in MQTT library. If you have not ported the SOCKETS library (Appendix E), comment out the line that calls SOCKETS_Init()in function SYSTEM_Init(), in file $AFR_HOME/lib/utils/aws_system_init.c.

### Test Setup

1. In $AFR_HOME/tests/[vendor]/[board]/common/application_code/main.c, uncomment the call to FreeRTOS_IPInit() in main(). By default, the IP address is acquired by DHCP. If DCHP fails or you do not want to use DHCP, you must set a static IP address in $AFR_HOME/tests/[vendors]/[board]/common/application_code/main.c. The following variables must be set to valid values of your actual network:
Network configuration variables | Description
uint8_t ucMACAddress[6]
uint8_t ucIPAddress[4]
uint8_t ucNetMask[4]
uint8_t ucGatewayAddress[ 4 ] uint8_t ucDNSServerAddress[ 4 ] uint8_t ucMACAddress[6]
2. In $AFR_HOME/tests/[vendor]/[board]/common/config_files/FreeRTOSIPConfig.h set the ipconfigUSE_NETWORK_EVENT_HOOK macro to 1.

Copyright © 2018 Amazon Web Services, Inc. and/or its affiliates. All rights reserved. | 30
3. In $AFR_HOME/tests/[vendor]/[board]/common/application_code/main.c add the code below at the start of vApplicationIPNetworkEventHook():

### Test Execution

1. Build and execute the test project.
2. If “Network connection successful” appears in the UART console, then the Ethernet driver has successfully connected to the network and this test is complete.

if (eNetworkEvent == eNetworkUp)
{
configPRINT("Network connection successful.\n\r"); }

Copyright © 2018 Amazon Web Services, Inc. and/or its affiliates. All rights reserved. | 31

## 5.5 Appendix E: Secure Sockets

### Description

The Secure Sockets library API is based on the Berkeley sockets API. It provides the API functions necessary to create and configure a TCP socket, connect to an MQTT broker, and send and receive TCP data.

The library is called Secure Sockets as it also encapsulates TLS functionality. To create a TLS protected socket the application writer need only creates a standard TCP socket, then uses a setsockopt call make the socket use TLS.

If your target hardware does not offload TCP/IP functionality to a separate network chip then use the FreeRTOS+TCP TCP/IP stack. A Secure Sockets implementation already exists for the FreeRTOS+TCP TCP/IP stack used in conjunction with mbedTLS – so if you are using those libraries no porting is necessary, but the Secure Sockets tests must still be executed and pass.

### Pre-requisites

1. If you are using Wi-Fi for network connectivity: A port of the Wi-Fi management library as described in Appendix C: Wi-Fi Management.
2. If you are using the FreeRTOS+TCP TCP/IP stack: A port of the FreeRTOS+TCP library as described in Appendix D: FreeRTOS TCP/IP Stack.

### Preparing the IDE Project

In all steps below, add source files to the IDE project from their existing location on the disk (by reference) – do not create duplicate copies of source files on the disk:

1. If you use the FreeRTOS+TCP TCP/IP stack, add $AFR_HOME/lib/secure_sockets/portable/freertos_plus_tcp/aws_secure_sockets.c to the [project_top_level]/lib/aws/secure_sockets folder of the IDE project.
2. If you use your own port, add $AFR_HOME/lib/secure_sockets/portable/[vendor]/[board]/aws_secure_sockets.c to the [project_top_leve]/lib/aws/secure_sockets folder of the IDE project.
3. Add
$AFR_HOME/tests/common/secure_sockets/portable/[vendor]/[board]/aws_test_tcp_port able.h and
$AFR_HOME/tests/common/secure_sockets/portable/[vendor]/[board]/aws_test_tcp.c to the [project_top_level]/application_code/common_tests/secure_sockets folder of the IDE project.

### Porting

If you use the FreeRTOS+TCP TCP/IP stack then no porting is necessary.

If your target hardware offloads TCP/IP functionality to a separate network chip then it is necessary to implement all the functions for which stubs already exist in $AFR_HOME/lib/secure_sockets/portable/[vendor]/[board]/aws_secure_sockets.c.

Copyright © 2018 Amazon Web Services, Inc. and/or its affiliates. All rights reserved. | 32

$AFR_HOME/lib/include/aws_secure_sockets.h contains the information necessary to create the implementations.

Since the MQTT library is not used for running Wi-Fi tests, comment out the calls to BUFFERPOOL_Init() and MQTT_AGENT_Init() from SYSTEM_Init(), which is located in $AFR_HOME/lib/utils/aws_system_init.c. Make sure the call to SOCKETS_init() is uncommented.

### Test Setup

If you use AWS IoT Device Tester for Amazon FreeRTOS to run tests you don’t need to perform the following setup steps. See https://aws.amazon.com/freertos/device-tester for more information.

1. The Secure Sockets tests require an echo server to be present on the network. For your convenience, the AFQ tests distribution contains a suitable echo server, written in Go, in the $AFR_HOME/tools/echo_server directory.

To start the echo server:

a) Ensure the latest version of Go is installed on the computer that will run the echo server (the server host). Go can be installed from https://golang.org/dl/
b) Copy $AFR_HOME/tools/echo_server/echo_server.go onto the server host.
c) Start the server by typing: “go run echo_server.go”
d) In $AFR_HOME/tests/common/include/aws_test_tcp.h, set the parameters shown in the table below to the IP address of the server host. The value 192.168.0.200 is an example only.
Echo Server IP address | Example value if address is 192.168.0.200
tcptestECHO_SERVER_ADDR0 | 192
tcptestECHO_SERVER_ADDR1 | 168
tcptestECHO_SERVER_ADDR2 | 0
tcptestECHO_SERVER_ADDR3 | 200

To test that the echo server is working, open a command prompt on a computer on the same network and type “telnet 192.168.0.200 9001” from a Windows host, or “nc 192.168.0.200 9001” from a Linux host. Again, use the correct IP address for the server host – 192.168.0.200 is used as an example only.

It may be necessary to adjust the firewall settings on the server host to enable the MCU to connect.

2. Set the tcptestTCP_ECHO_CLIENT_PORT macro in $AFR_HOME/tests/common/include/aws_test_tcp.h to the port on which the echo server is listening. The provided echo server listens on port 9001. If you have problems connecting to port 9001 due to corporate network security policies, you can change the listening port in the echo server code to a port that is not restricted by your company’s security policy.

Copyright © 2018 Amazon Web Services, Inc. and/or its affiliates. All rights reserved. | 33
3. Set the tcptestSECURE_SERVER macro to 0 in
$AFR_HOME/tests/common/include/aws_test_tcp.h to run the socket tests without TLS.
4. Set the testrunnerFULL_TCP_ENABLED macro to 1 in $AFR_HOME/tests/[vendor]/[board]/common/config_files/aws_test_runner.config.h to enable the sockets tests.
5. Enable the testing task in
$AFR_HOME/tests/[vendor]/[board]/common/application_code/main.c by deleting the #if 0 and #endif compiler directives, in vApplicationIPNetworkEventHook ( void ). This change is required for all the remaining libraries to be ported in this document.

Dependency on TLS
The test set for this library (Secure Sockets) includes some tests that require TLS which is described later in this document. The functionality verified by these tests is exercised when tcptestSECURE_SERVER macro is set to 1. You MUST come back to run this subset of the Secure Socket tests after TLS library porting is completed. A TLS capable echo server should be setup before running these tests ( Appendix M: TLS Server Setup).

### Test Execution

1. Build and execute the test project.
2. View the test results in the UART console. If all the tests pass, then testing is complete. Save the test results by cutting and pasting them from the UART console into a text file, and move to the next section.

Example test results output:

…

Alternatively, you can use AWS IoT Device Tester for Amazon FreeRTOS to test your implementation of Secure Sockets.

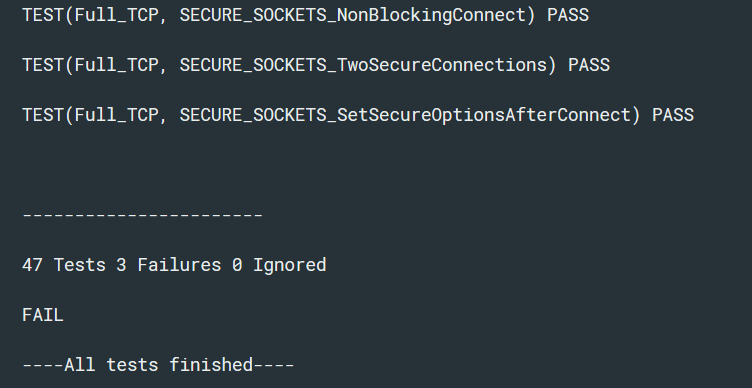
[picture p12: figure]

Copyright © 2018 Amazon Web Services, Inc. and/or its affiliates. All rights reserved. | 34

Copyright © 2018 Amazon Web Services, Inc. and/or its affiliates. All rights reserved. | 35

## 5.6 Appendix F: PKCS #11

### Description

Amazon FreeRTOS uses the open standard PKCS #11 “CryptoKi” API as the abstraction layer for cryptographic operations, including:

- Encryption and decryption.
- Storage and enumeration of X.509 certificates.
- Storage and management of cryptographic keys.

See the open standard PKCS #11 Cryptographic Token Interface Base Specification:

http://docs.oasis-open.org/pkcs11/pkcs11-base/v2.40/os/pkcs11-base-v2.40-os.html

Storing private keys in general purpose flash memory can be convenient in evaluation and rapid prototyping scenarios. However, when it comes to production scenarios, we recommend the use of dedicated cryptographic hardware in order to reduce the threats of data theft and device duplication. Cryptographic hardware includes components with features that prevent cryptographic secret keys from being exported. In order to use such hardware with Amazon FreeRTOS, the PKCS #11 API must be ported to it.

### Pre-requisites

1. A test project that was created in accordance with the instructions provided in the body of this document, and that is building vendor-supplied storage drivers that are suitable for sensitive data.
2. An implementation of configPRINT_STRING() that was created and tested as described in Appendix A.
3. A validated FreeRTOS kernel configuration, as described in Appendix B: FreeRTOS kernel.

### Preparing the IDE Project

In all steps below, add source files to the IDE project from their existing location on the disk (by reference) – do not create duplicate copies of source files on the disk:

1. Add $AFR_HOME/lib/pkcs11/portable/[vendor]/[board]/aws_pkcs11_pal.c to the [project_top_level]/lib/aws/pkcs11 folder of the test project.
2. Add the PKCS #11 library header files from $AFR_HOME/lib/third_party/pkcs11 to the [project_top_level]/lib/third_party/pkcs11 folder of the test project.
3. Add the PKCS #11 tests from $AFR_HOME/tests/common/pkcs11/aws_test_pkcs11.c to the [project_top_level]/application_code/common_tests/pkcs11 folder folder of the test project.
4. Add the implementation of PKCS #11 for mbedTLS $AFR_HOME/lib/pkcs11/mbedtls/aws_pkcs11_mbedtls.c to the [project_top_level]/lib/pkcs11 folder of the test project
5. Import the CRYPTO abstraction wrapper file for mbedTLS $AFR_HOME/lib/crypto/aws_crypto.c to the [project_top_level]/lib/crypto folder of the test project.
6. Add the mbedTLS library itself from $AFR_HOME/lib/third_party/mbedtls/library into the [project_top_level]/lib/third_party/mbedtls/source folder of the test project.

Copyright © 2018 Amazon Web Services, Inc. and/or its affiliates. All rights reserved. | 36
7. Add the mbedTLS library header file from $AFR_HOME/lib/third_party/mbedtls/include into the [project_top_level]/lib/third_party/mbedtls/include folder of the test project.
8. Add both $AFR_HOME/lib/third_party/mbedtls/include and $AFR_HOME/lib/third_party/pkcs11 to the compiler’s include path.

### Porting

1. Porting the PKCS #11 API functions

The PKCS #11 API is dependent on the implementation of cryptographic primitives such as SHA256 hashing and ECDSA signing. The Amazon FreeRTOS implementation of PKCS #11 uses the cryptographic primitives implemented in the mbedTLS library, for which a port is already provided. Modifying the existing PKCS #11 port is required if you wish to use a different software implementation of the cryptographic primitives (i.e., other than mbedTLS), or if your target hardware offloads crypto to a separate module.

2. Porting the PKCS #11 Platform Abstraction Layer (PAL) for device specific certificate and key storage

If you decide to use the Amazon FreeRTOS implementation of PKCS #11, there is a relatively small amount of customization required in order to read and write cryptographic objects to non-volatile memory (NVM) (for example, onboard flash memory).

Cryptographic objects should be stored in a section of NVM that is not initialized/erased on device reprogramming. Users of the PKCS #11 library should be able to provision devices with credentials, and then reprogram the device with a new application which accesses these credentials via the PKCS #11 interface.

PKCS #11 PAL ports must provide a location to store device client certificate, device client private key, device client public key, trusted root CA, and a code verification public key (or certificate containing the code verification public key) for secure bootloader and over-the-air updates.

$AFR_HOME/lib/pkcs11/portable/[vendor][board]/aws_pkcs11_pal.c contains stubs for the PAL functions, of which you must provide ports for at least the functions listed in the table below:

Function | Description
PKCS11_PAL_SaveObject | Writes data to non-volatile storage
PKCS11_PAL_FindObject | Uses a PKCS #11 CKA_LABEL to search for a corresponding PKCS #11 object in non-volatile storage, and returns that object’s handle if it exists.
PKCS11_PAL_GetObjectValue | Retrieves the value of an object, given the handle.
PKCS11_PAL_GetObjectValueCleanup | Cleanup for the PKCS11_PAL_GetObjectValue call. May be used to free memory allocated in PKCS11_PAL_GetObjectValue call.

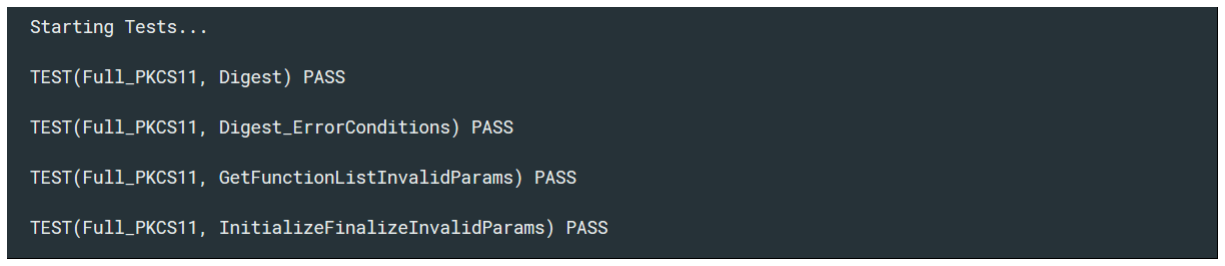
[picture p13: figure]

Copyright © 2018 Amazon Web Services, Inc. and/or its affiliates. All rights reserved. | 37
3. Implement mbedtls_hardware_poll()

You only need to port this function if you plan to use Amazon FreeRTOS’ PKCS#11 implementation and the mbedTLS library for underlying cryptographic and TLS support.

TCP/IP and TLS require cryptographic pseudo-random number generation (PRNG) for sequence number and key generation, respectively. A hardware entropy source is important for seeding the PRNG. For the mbedTLS library to work, you MUST implement mbedtls_hardware_poll() which allows the mbedTLS library to seed its PRNG using your board’s entropy source. This function is located in $AFR_HOME/lib/pkcs11/portable/[vendor][board]/aws_pkcs11_pal.c

Note that if the port board does not contain a cryptographically accepted random number source, it may be necessary to follow the entropy seeding approach described in the mbedTLS porting guide below.

For more information see, https://docs.mbed.com/docs/mbed-os-handbook/en/5.2/advanced/tls_porting. (https://docs.mbed.com/docs/mbed-os-handbook/en/5.2/advanced/tls_porting/)

Since the MQTT library is not used for running PKCS11 tests, comment out the lines that call BUFFERPOOL_Init(), MQTT_AGENT_Init()in function SYSTEM_Init()in file $AFR_HOME/lib/utils/aws_system_init.c. Bufferpool and mqtt_agent are used in MQTT library. If you have not ported the SOCKETS library (Appendix E), comment out the line that calls SOCKETS_Init()in function SYSTEM_Init(), in file $AFR_HOME/lib/utils/aws_system_init.c.

### Test Setup

If you use AWS IoT Device Tester for Amazon FreeRTOS to run tests you don’t need to perform the following setup steps. See https://aws.amazon.com/freertos/device-tester for more information.

1. Enable the PKCS 11 test by setting the testrunnerFULL_PKCS11_ENABLED macro to 1 in $AFR_HOME/tests/[vendor]/[board]/common/config_files/aws_test_runner_config.h.

### Test Execution

Build and execute the project. The UART output indicates how many tests have run and completed successfully. Copy the results from the terminal and save it to a text file.

Example of the test results output:

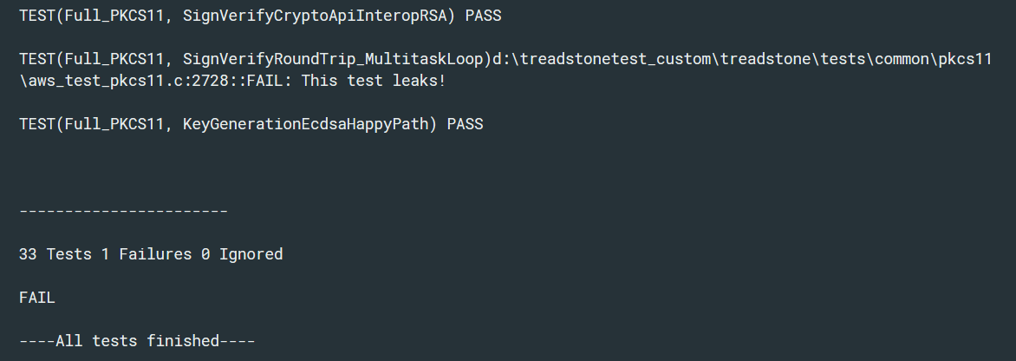
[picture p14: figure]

Copyright © 2018 Amazon Web Services, Inc. and/or its affiliates. All rights reserved. | 38

…

Alternatively, you can use AWS IoT Device Tester for Amazon FreeRTOS to test your implementation of PKCS#11.

Copyright © 2018 Amazon Web Services, Inc. and/or its affiliates. All rights reserved. | 39

## 5.7 Appendix G: TLS

### Description

The AWS IoT Core MQTT broker only accepts mutually authenticated TLS connections. Amazon FreeRTOS can use either mbedTLS, in which case no porting is necessary, or an off-chip TLS implementation, such as those found on some network co-processors. To allow both options the TLS library is not accessed directly, but through a TLS abstraction layer.

In all cases, the TLS tests must be executed and pass. Preparing the tests requires IoT device configuration in the AWS cloud and certificate and key provisioning on the target hardware.

### Pre-requisites

1. A port of the Secure Sockets library, as described in Appendix E: Secure Sockets.
2. A port of the PKCS #11 library, as described in Appendix F: PKCS #11.
3. An AWS account.

### Preparing the IDE Project

1. Add the TLS abstraction implementation $AFR_HOME/lib/tls/aws_tls.c or $AFR_HOME/lib/tls/portable/[vendor]/[board]/aws_tls.c (if your target hardware offloads TLS to a separate processor) to the [project_top_leve]/lib/aws/tls folder of the test project.
2. Add the TLS tests file $AFR_HOME/tests/common/tls/aws_test_tls.c to the [project_top_level]/application_code/common_tests/tls folder of the test project.
3. Enable the tests by setting the testrunnerFULL_TLS_ENABLED macro to 1 in $AFR_HOME/tests/[vendor]/[board]/common/config_files/aws_test_runner_config.h.

### Porting

If your target hardware offloads TLS functionality to a separate network chip then it is necessary to implement all the TLS abstraction layer functions in the table below. $AFR_HOME/lib/include/aws_tls.h contains the information necessary to create the implementations. Save the created file as
$AFR_HOME/lib/tls/portable/[vendor]/[board]/aws_tls.c
Function | Description
TLS_Init | Initialize the TLS context
TLS_Connect | Negotiate TLS and connect to the server
TLS_Recv | Read the requested number of bytes from the TLS connection
TLS_Send | Write the requested number of bytes to the TLS connection
TLS_Cleanup | Free resources consumed by the TLS context

Since the MQTT library is not used for running Wi-Fi tests, comment out the calls to BUFFERPOOL_Init() and MQTT_AGENT_Init() from SYSTEM_Init(), which is located

Copyright © 2018 Amazon Web Services, Inc. and/or its affiliates. All rights reserved. | 40

in $AFR_HOME/lib/utils/aws_system_init.c. Make sure the call to SOCKETS_init() is uncommented.

### Test Setup

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

The tests in this section require use of the online AWS console, where your target hardware will be represented as a ‘thing’, and communicate with AWS via a custom MQTT endpoint that is tied to your AWS account.

The steps below create the certificates and keys necessary to complete qualification tests.

The tests require the created certificates and keys to be built into the target hardware’s executable image. That is convenient in this test scenario, but is not recommended for production scenarios, where the keys should be kept in hardened storage.

Certificate Formatting Tool: It is necessary to convert the certificates and keys to C strings before building them into the executable image. The AFQ tests include a tool for that purpose. To convert certificate and key pairs into C strings:

a. Open $AFR_HOME/tools/certificate_configuration/PEMfileToCString.html in a web browser.
b. Follow the instructions on the opened web page to load the certificate and private key.
c. Once loaded, follow the instruction in the opened web page to convert the opened certificate and private key to a formatted C string.
1. Set the clientcredentialMQTT_BROKER_ENDPOINT[] variable in $AFR_HOME/tests/common/include/aws_clientcredential.h to the custom end point of your AWS account – this is the URL the TLS tests connect to.

To find your custom end point, use the URL https://aws.amazon.com/iot/ to log into your AWS account, then click the “Settings” link in the bottom left corner of the screen to open the settings window – the customer end point is displayed at the top of the settings window.

2. Noting the information below about the information you need to record during the process, follow the steps in the AWS IoT Getting Started tutorial to create the resources in AWS IoT that will represent your target hardware (Thing, Certificate and Policies).
a. Start here: https://docs.aws.amazon.com/iot/latest/developerguide/iot-console-signin.html, (https://docs.aws.amazon.com/iot/latest/developerguide/iot-console-signin.html) and continue through each of the steps of the tutorial until you complete “Attach your Certificate to a Thing”. See notes below for additional guidance about these steps.
b. During this process,
- Set the clientcredentialIOT_THING_NAME variable in $AFR_HOME/tests/common/include/aws_clientcredential.h to the name you assigned your ‘thing’ (the thing name).

Copyright © 2018 Amazon Web Services, Inc. and/or its affiliates. All rights reserved. | 41
- The steps on the link above include the creation of a certificate. Download and save all three files that are generated during that process.
- The steps on the link above include creating a policy. Use the following policy to attach to the certificate:

This policy will allow all IoT actions on all resources. That is convenient in a test and evaluation scenario but is not recommended for production scenarios.

3. Prepare certificate/key pairs for various tests for the TLS library.

AWS IoT can use AWS IoT-generated certificates or certificates signed by a CA certificate for device authentication. In order to run the various tests, you will need to create multiple credentials as listed below:

a. Generate a certificate by AWS IoT. (RSA Certificate)
b. Generate a certificate from a CSR (Certificate Signing Request). (ECDSA cert, Malformed cert)
c. Generate a certificate from a registered CA. (Untrusted, BYOC certificate)

The credentials for the types listed above are described in detail in following table. All of the testing client certificates and private keys listed above must be stored in:

$AFR_HOME/tests/common/aws_clientcredential_keys.h

$AFR_HOME/tests/common/aws_test_tls.h

Cert/Key Variables | Description
keyCLIENT_CERTIFICATE_PEM | Device certificate used for AWS cloud communication. It is also used in TLS_ConnectRSA() test. You can set this up using AWS Console.
keyCLIENT_PRIVATE_KEY_PEM | Device private key used for AWS cloud communication. It is also used in TLS_ConnectRSA() test. You can set this up using AWS Console.
tlstestCLIENT_CERTIFICATE_PEM_EC | Certificate for P-256 elliptic curve key. It is used in TLS_ConnectEC() test.

{
"Effect": "Allow",

"Action": "iot:*",

"Resource": "*"

}

Copyright © 2018 Amazon Web Services, Inc. and/or its affiliates. All rights reserved. | 42
tlstestCLIENT_PRIVATE_KEY_PEM_EC | A p-256 elliptic curve key. It is used in TLS_ConnectEC() test.
tlstestCLIENT_CERTIFICATE_PEM_MALFORMED | A RSA or ECDSA certificate that has a field modified. Used in TLS_ConnectMalformedCert() test.
tlstestCLIENT_UNTRUSTED_CERTIFICATE_PEM | A certificate is not trusted (not registered) by AWS IoT. Used in TLS_ConnectUntrustedCert().
tlstestCLIENT_UNTRUSTED_PRIVATE_KEY_PEM | The private key correspond to the untrusted certificate.
tlstestCLIENT_BYOC_CERTIFICATE_PEM | A certificate created by a CA (registered to AWS IoT). Used in TLS_ConnectBYOCCredentials().
tlstestCLIENT_BYOC_PRIVATE_KEY_PEM | The private key corresponding to the BYOC certificate.

Setup for RSA certificate/private key used in TLS_ConnectRSA() :
This pair of certificate/key is generated in Test Setup Step 2. The three files you downloaded during that “Thing” creation process will be used here.

Format the certificate and the private key with the formatting tool and copy them to macros

keyCLIENT_CERTIFICATE_PEM

keyCLIENT_PRIVATE_KEY_PEM

in file $AFR_HOME/tests/common/aws_clientcredential_keys.h.

Setup for ECDSA certificate/private key used in TLS_ConnectEC():

OpenSSL is an open source toolkit for TLS protocol. (https://www.openssl.org/). We will use openssl in examples of generating certificates below. Please use TLS V1.2. You can download it here: https://www.openssl.org/source/

1) Create a CSR with openssl:
a) openssl ecparam -name prime256v1 -genkey -noout -out p256_privatekey.pem
b) openssl req –new –key p256_privatekey.pem –out csr.csr
2) Create a certificate with the AWS IoT console:
a) On the AWS IoT / Security / Certificate page, click “Create” in upper right-hand corner
b) Click “Create with CSR” and upload the .csr file created in step 1.
c) Download the cert .pem file, activate it and attach the same policy you used when setting up the RSA certificate.
d) Attach the certificate to the IoT thing created when you set up the “Thing”.
3) Format the certificate and the private key using the formatting tool.
4) Copy the created cert and private key to the following variables in $AFR_HOME/tests/common/aws_test_tls.h:
a) tlstestCLIENT_CERTIFICATE_PEM_EC
b) tlstestCLIENT_PRIVATE_KEY_PEM_EC

Copyright © 2018 Amazon Web Services, Inc. and/or its affiliates. All rights reserved. | 43
5) In $AFR_HOME/tests/common/tls/aws_test_tls.c, set the tlstestMQTT_BROKER_ENDPOINT_EC variable to the same AWS IoT message broker endpoint address in TLS Test Setup Step 1.

Setup for Malformed certificate used in TLS_ConnectMalformedCert():
The purpose of the test is to be able to use a malformed certificate to authenticate with the server. Random modification of a certificate will most likely be rejected by x509 certificate verification before the connection request is sent out. We have a suggestion to setup this malformed certificate: modifying the issuer of the certificate.

See Appendix S: Modify issuer in a certificate for process details.

Setup for BYOC (Bring You Own Certificate) certificate used in TLS_ConnectBYOCCredentials():
1) Create your own certificate with a valid rootCA/CA chain. See example in Appendix Q: Instructions to Create a BYOC (ECDSA).
2) Register CAs and your own certificate in the AWS IoT console: IoT Core / Secure / Certificates / Create / Get started.
3) Format the certificate and the private key using the formatting tool.
4) Copy the certificate and private key strings to the following variables in $AFR_HOME/tests/common/aws_test_tls.h:
a) tlstestCLIENT_BYOC_CERTIFICATE_PEM
b) tlstestCLIENT_BYOC_PRIVATE_KEY_PEM

Setup for Untrusted certificate used in TLS_ConnectUntrustedCert():
1) Create your own certificate with valid rootCA/CA chain. See example in Appendix Q: Instructions to Create a BYOC (ECDSA).
2) Do not register them in AWS IoT console.
3) Format the certificate and the private key using the formatting tool.
4) Copy the cert and private key strings to the following variables in $AFR_HOME/tests/common/aws_test_tls.h:
a) tlstestCLIENT_UNTRUSTED_CERTIFICATE_PEM
b) tlstestCLIENT_UNTRUSTED_PRIVATE_KEY_PEM

### Test Execution

1. Build and execute the test project.
2. View the test results in the UART console. If all the tests pass, then testing is complete. Save the test results by cutting and pasting them from the UART console into a text file, and move to the next section.

Example of the test results output:

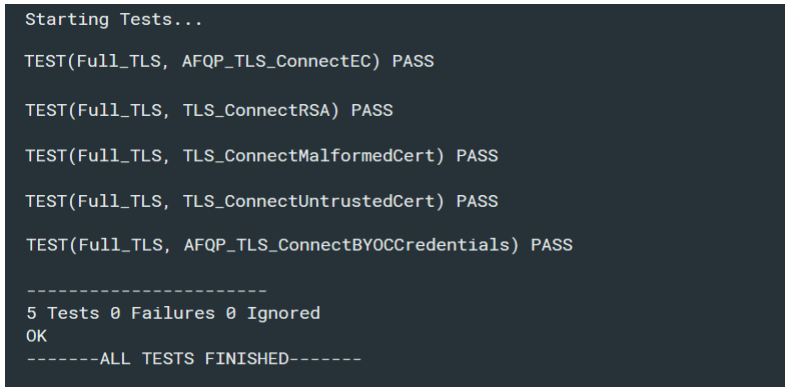
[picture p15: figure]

Copyright © 2018 Amazon Web Services, Inc. and/or its affiliates. All rights reserved. | 44

Once TLS porting and verification is completed, note that you must go back to run a subset of the Secure Socket tests which depend on this functionality i.e. when tcptestSECURE_SERVER macro is set to 1. See Dependency on TLS in the Secure Sockets porting section.

Alternatively, you can use AWS IoT Device Tester for Amazon FreeRTOS to test your implementation of TLS.

Copyright © 2018 Amazon Web Services, Inc. and/or its affiliates. All rights reserved. | 45

## 5.8 Appendix H: MQTT

### Description

Communication between IoT devices and AWS IoT Core (the MQTT broker) uses the MQTT protocol. The MQTT library that implements the protocol does not need to be ported, but does need to pass all the MQTT tests.

The MQTT library has a dependency on the Buffer Pool library, which is used to allocate the memory necessary to hold MQTT packets.

### Pre-requisites

1. A port of the Secure Sockets library, as described in Appendix E: Secure Sockets.
2. A port of the PKCS #11 library, as described in Appendix F: PKCS #11.
3. A port of the TLS library, as described in Appendix G: TLS.
4. An AWS account.
5. An IoT thing created in AWS cloud and its associated credential information. (Refer to TLS_Test_Setup_Step_1, TLS_Test_Setup_Step_2 and RSA_Certificate_Setup)

### Preparing the IDE Project

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

1. Add the MQTT library source files from $AFR_HOME/lib/mqtt into the [project_top_level]/lib/aws/mqtt folder of the test project.
2. Add the Bufferpool source files from $AFR_HOME/lib/bufferpool into the [project_top_level]/lib/bufferpool folder of the test project.
3. Add the MQTT test source files from $AFR_HOME/tests/common/mqtt/ to [project_top_level]/application_code/common_tests/mqtt folder of the test project.
4. Uncomment all the initialization functions called from SYSTEM_Init() within $AFR_HOME/lib/utils/aws_system_init.c.

### Porting

In order to enable MQTT functionality, uncomment the calls to BUFFERPOOL_Init() and MQTT_AGENT_Init() from SYSTEM_Init(), which is located in $AFR_HOME/lib/utils/aws_system_init.c. Make sure the call to SOCKETS_init() is also still uncommented.

There is no additional porting required for this library.

### Test Setup

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

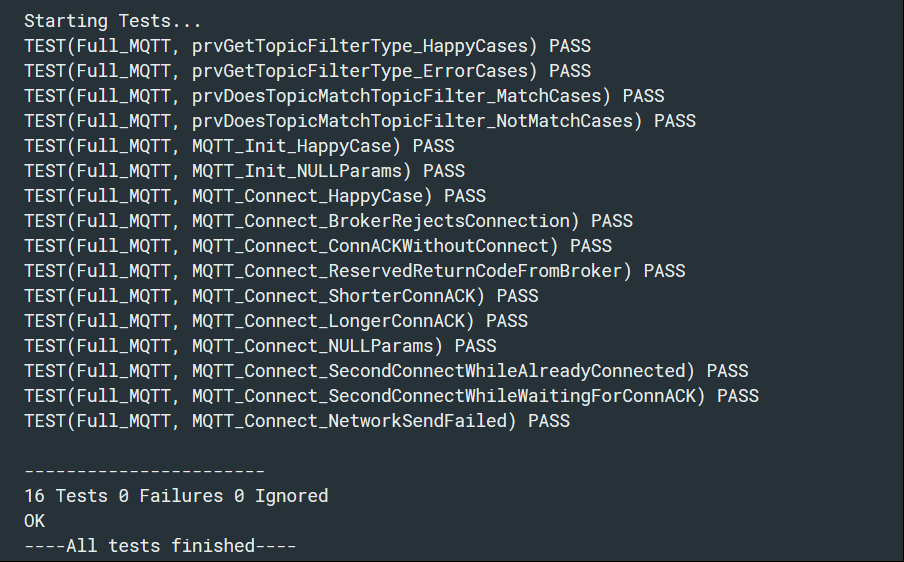
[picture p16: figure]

Copyright © 2018 Amazon Web Services, Inc. and/or its affiliates. All rights reserved. | 46

These tests require the certificates and keys that were created prior to testing the TLS library.

1. Enable the MQTT tests by setting testrunnerFULL_MQTT_ENABLED to 1 in $AFR_HOME/tests/[vendor]/[board]/common/config_files/aws_test_runner_config.h

### Test Execution

1. Build and execute the test project.
2. View the test results in the UART console. If all the tests pass, then testing is complete. Save the test results by cutting and pasting them from the UART console into a text file.

Example of the test results output:

Alternatively, you can use AWS IoT Device Tester for Amazon FreeRTOS to test MQTT.

Copyright © 2018 Amazon Web Services, Inc. and/or its affiliates. All rights reserved. | 47

## 5.9 Appendix I: OTA Updates

### Description

The Amazon FreeRTOS over-the-air (OTA) update feature enables you to:

- Deploy new firmware images to a single device, a group of devices, or your entire fleet.
- Deploy firmware to devices as they are added to groups, are reset, or are re-provisioned.
- Verify the authenticity and integrity of new firmware after it has been deployed to devices.
- Monitor the progress of a deployment.
- Debug a failed deployment.
- Digitally sign firmware using the AWS Signer service.

Amazon FreeRTOS devices must enforce cryptographic code-sign verification of the OTA firmware images they receive. Regarding algorithm selection, we recommend the use of the Elliptic-Curve Digital Signature Algorithm (ECDSA), the NIST P256 curve, and a SHA-256 hash

### Pre-requisites

1. A Bootloader that can support OTA update as described in Appendix J: Bootloader.
2. A port of the PKCS #11 library, as described in Appendix F: PKCS #11.
3. A port of the TLS library, as described in Appendix G: TLS.

### Preparing the IDE Project

1. Add the OTA library files from $AFR_HOME/lib/ota into the IDE project under the [project_top_level]/lib/aws/ota virtual folder.
2. Import the OTA library PAL files,
$AFR_HOME/lib/ota/portable/[vendor]/[board]/aws_ota_pal.c into the IDE project under the [project_top_level]/lib/aws/ota virtual folder.
3. Import the OTA tests,
- $AFR_HOME/tests/common/ota/aws_test_cbor.c
- $AFR_HOME/tests/common/ota/aws_test_ota_agent.c
- $AFR_HOME/tests/common/aws_test_pal.c
into the IDE project under the [project_top_level]/application_code/common_tests/ota virtual folder.
4. Add the OTA Update demo from $AFR_HOME/demos/common/ota/aws_ota_update_demo.c into the IDE project under the [project_top_level]/application_code/common_tests/ota virtual folder.

### Porting

Amazon FreeRTOS defines an OTA platform abstraction layer (PAL) in order to ensure that the OTA library can be used on a wide variety of hardware. The OTA PAL interface is listed below.

Copyright © 2018 Amazon Web Services, Inc. and/or its affiliates. All rights reserved. | 48
Function | Description
prvAbort | Aborts an OTA update.
prvCreateFileForRx | Creates a new file to store the data chunks as they are received.
prvCloseFile | Closes the specified file. This may authenticate the file if storage that implements cryptographic protection is being used.
prvWriteBlock | Writes a block of data to the specified file at the given offset. Returns the number of bytes written on success or negative error code.
prvActivateNewImage | Activates or launches the new firmware image. For some ports, if the device is programmatically reset synchronously, this function may not return.
prvSetImageState | Does what is required by the platform to accept or reject the most recent OTA firmware image (or bundle). Refer to your respective board (platform) details and architecture to determine how to implement this function.
prvGetImageState | Gets the state of the OTA update image.

The following two functions are optional if a device has built-in support for them. If not then they need to be implemented in the PAL.

Function | Description
prvCheckFileSignature | Verifies the signature of the specified file.
prvReadAndAssumeCertificate | Reads the specified signer certificate from the file system and returns it to the caller.

### Test Setup

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

The OTA AFQ tests are split into the following two categories: Agent and PAL module tests, and end-to-end functional tests.

1. Agent/PAL tests
a. Enable the OTA Agent/PAL tests by setting the following macros to 1 in $AFR_HOME/tests/[vendor]/[board]/common/config_files/aws_test_runner_config.h:
- testrunnerFULL_OTA_AGENT_ENABLED
- testrunnerFULL_OTA_PAL_ENABLED
b. Select a signing certificate that is appropriate for your device from $AFR_HOME/tests/common/ota/test_files.
Each board has its specific way to provision a device. The certificate will be used for verification in OTA tests.
Three types of signing certificates are available in the test code. These include RSA/SHA1, RSA/SHA256 and ECDSA/SHA256. Out of the three, the use of ECDSA/SHA256 is recommended for OTA updates. The other two are available for existing platforms only. If you have a different

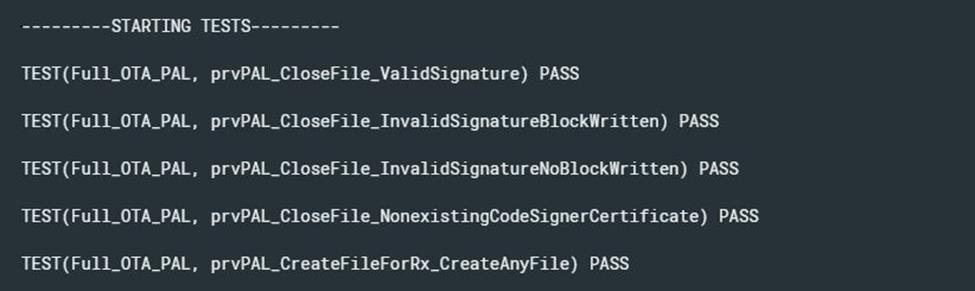
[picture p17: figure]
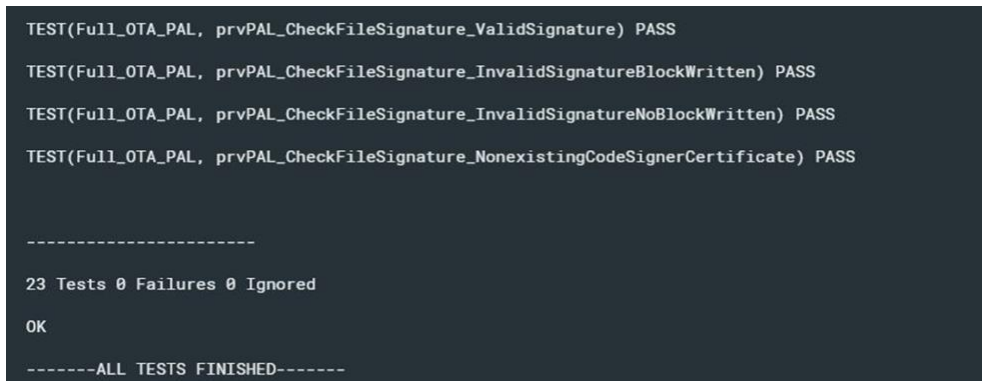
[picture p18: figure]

Copyright © 2018 Amazon Web Services, Inc. and/or its affiliates. All rights reserved. | 49

scheme that is not included in the aforementioned three schemes, then please contact your Qual-Rep.

2. End-to-end OTA tests
These tests will be conducted by manually running python scripts located in $AFR_HOME/tools/ota_e2e_test/
a. Enable the OTA end-to-end tests by setting the following macros to 1 in $AFR_HOME/tests/[vendor]/[board]/common/config_files/aws_test_runner_config.h:
- testrunner_OTA_END_TO_END_ENABLED
b. Follow the instructions in $AFR_HOME/tools/ota_e2e_test/README.md

### Test Execution

1. Agent/PAL tests
a. Build and execute the test project.
b. View the test results in the UART console. If all the tests pass, then testing is complete. Save the test results by cutting and pasting them from the UART console into a text file.

Example of the test results output:

…

Copyright © 2018 Amazon Web Services, Inc. and/or its affiliates. All rights reserved. | 50
2. End-to-end OTA Tests
a. Make sure there are no changes to aws_demo_runner.c, aws_clientcredential.h, aws_clientcredential_keys.h, aws_application_version.h, and aws_ota_codesigner_certificate.h from what was used to run the agent/PAL tests.
b. Follow the example listed in $AFR_HOME/tools/ota_e2e_test/README.md to run the ota end-to-end test script.

Alternatively, you can use AWS IoT Device Tester for Amazon FreeRTOS to test OTA.

Copyright © 2018 Amazon Web Services, Inc. and/or its affiliates. All rights reserved. | 51

## 5.10 Appendix J: Bootloader

Amazon FreeRTOS provides a demo bootloader as an example for the Microchip Curiosity PIC32MZEF platform. It may be ported to other platforms where applicable. However there is the option for users to provide their own bootloader. In order for such a bootloader to work with the OTA functionality, the following requirements must be adhered to:

1. The bootloader shall be stored in non-volatile memory so it cannot be overwritten.
2. The bootloader shall verify the cryptographic signature of the downloaded application image. Signature verification must be consistent with the OTA image signer. See Appendix I: OTA Updates for supported signatures.
3. The bootloader shall not allow rolling back to a previously installed application image.
4. The bootloader shall maintain at least one image that can be booted.
5. If the MCU contains more than one image then the image that is executed shall be the latest (newest). The newest version can be determined based on implementation, for example a user defined sequence number, application version etc. As per other requirements, this can only be the case until a newer version has been verified and proven functional.
6. If the MCU cannot verify any images then it shall place itself into a controlled benign state. In this state it prevents itself from being taken over by ensuring no actions are performed.
7. These requirements shall not be breached even in the presence of an accidental or malicious write to any MCU memory location (key store, program memory, RAM, etc.)
8. The bootloader shall support self-test of a new OTA image. If test execution fails, the bootloader shall roll back to the previous valid image. If test execution succeeds, the image shall be marked valid and the previous version erased.

The state of the application must be set by the OTA PAL as described in the user documentation at https://docs.aws.amazon.com/freertos/latest/userguide/freertos-ota-dev.html

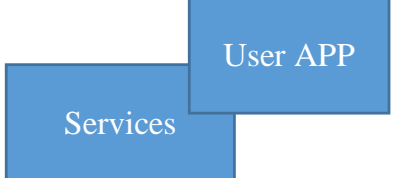
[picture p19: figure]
Services; User APP

Copyright © 2018 Amazon Web Services, Inc. and/or its affiliates. All rights reserved. | 52

## 5.11 Appendix K: Bluetooth Low Energy (Beta)

### Description

The Amazon FreeRTOS Bluetooth Low Energy (BLE) feature allows you to do WIFI provisioning and MQTT over BLE. It also provides users with higher level API that streamline the use of the BLE stack.

The AFR Bluetooth Library is layered as show below:

The AFQ tests target the wrapper layer, just above the Bluetooth Low Energy stack provided by the OEMs. Passing the AFQ tests should ensure the connectivity over BLE is working properly. As for how to use the Amazon FreeRTOS BLE library in your application, see more information here: https://docs.aws.amazon.com/freertos/latest/userguide/freertos-ble-library.html

This library is in beta. Please download the code from GitHub branch https://github.com/aws/amazonfreertos/tree/feature/ble-beta. (https://github.com/aws/amazon-freertos/tree/feature/ble-beta)

### Pre-requisites

1. A test project that was created in accordance with the instructions provided in the body of this document, and that is building vendor-supplied BLE drivers.
2. An implementation of configPRINT_STRING() that was created and tested as described in Appendix A.
3. A validated FreeRTOS kernel configuration, as described in Appendix B: FreeRTOS kernel.
4. A Raspberry PI 3b+ device.

OEM BLE stack

Low level wrappers for HAL BLE APIs

Middle ware

AFQ tests

Copyright © 2018 Amazon Web Services, Inc. and/or its affiliates. All rights reserved. | 53

### Preparing the IDE Project

1. Add all files in $AFR_HOME/lib/bluetooth_low_energy/portable/[vendor]/[board]/ directory to the [project_top_level]/lib/aws/bluetooth_low_energy virtual folder of the test IDE project.
2. Add the $AFR_HOME/lib/include/bluetooth_low_energy directory to the [project_top_level]/lib/aws/include folder of the test IDE project.
3. Add the file $AFR_HOME/tests/common/ble/aws_test_ble.c to the [project_top_level]/application_code/common_tests/ble virtual folder of the IDE project.
4. Enable the necessary BLE drivers in the $AFR_HOME/tests/[vendor]/[board]/common/application_code/main.c driver initializations of the relevant projects in the test project

### Porting

The API for BLE feature are defined in three files at $AFR_HOME/lib/include/bluetooth_low_energy directory.

- bt_hal_manager.h
- bt_hal_manager_adapter_ble.h
- bt_hal_gatt_server.h

See the comments in the files for description of APIs. The API that MUST be implemented are listed below.

GAP Common (bt_hal_manager.h)
pxBtManagerInit | pxEnable | pxDisable
pxGetDeviceProperty | pxSetDeviceProperty (All options mandatory except eBTpropertyRemoteRssi, eBTpropertyRemoteVersionInfo) | pxPair
| Y(All options mandatory expect eBTpropertyRemoteRssi, eBTpropertyRemoteVersionInfo)
pxRemoveBond | pxGetConnectionState | pxPinReply
pxSspReply | pxGetTxpower | pxGetLeAdapter
pxDeviceStateChangedCb | pxAdapterPropertiesCb | pxSspRequestCb
pxPairingStateChangedCb | pxTxPowerCb

GAP BLE (bt_hal_manager_adapter_ble.h)
pxRegisterBleApp | pxUnregisterBleApp | pxBleAdapterInit
pxStartAdv | pxStopAdv | pxSetAdvData
pxConnParameterUpdateRequest | pxRegisterBleAdapterCb | pxAdvStartCb

Copyright © 2018 Amazon Web Services, Inc. and/or its affiliates. All rights reserved. | 54
pxSetAdvDataCb | pxConnParameterUpdateRequestCb | pxCongestionCb

GATT Server (bt_hal_gatt_server.h)

pxRegisterServer | pxUnregisterServer | pxGattServerInit
pxAddService | pxAddIncludedService | pxAddCharacteristic
pxSetVal | pxAddDescriptor | pxStartService
pxStopService | pxDeleteService | pxSendIndication
pxSendResponse | pxMtuChangedCb | pxCongestionCb
pxIndicationSentCb | pxRequestExecWriteCb | pxRequestWriteCb
pxRequestReadCb | pxServiceDeletedCb | pxServiceStoppedCb
pxServiceStartedCb | pxDescriptorAddedCb | pxSetValCallbackCb
pxCharacteristicAddedCb | pxIncludedServiceAddedCb | pxServiceAddedCb
pxConnectionCb | pxUnregisterServerCb | pxRegisterServerCb

### Test Setup

The setup for BLE AFQ tests requires a Raspberry PI 3b+ as an external device to run the BLE tests.

The test computer sends test python file to the Raspberry and execute them remotely through ssh. Test results are returned through the ssh client.

At the same time, the test computer runs the tests on the DUT. Tests results are returned thought UART.

On the Raspberry PI:

Computer

SSH

Raspberry PI | DUT

UART

BLE

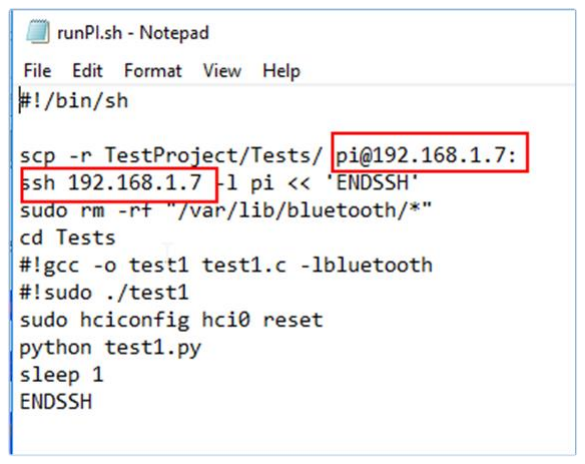
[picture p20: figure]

Copyright © 2018 Amazon Web Services, Inc. and/or its affiliates. All rights reserved. | 55
1. Make sure to order a Raspberry PI 3b+. Previous versions of devices don’t have Bluetooth support. You also need to order a memory card with it as Raspberry PI are not provided with a hard drive.
2. Raspberry PI 3b+: https://www.raspberrypi.org/products/raspberry-pi-3-model-b-plus/
3. Follow the step here to setup the Raspberry PI with Raspbian OS: https://projects.raspberrypi.org/en/projects/raspberry-pi-setting-up
4. Download bluez 5.50: https://git.kernel.org/pub/scm/bluetooth/bluez.git
5. Follow the README at the root to install on the Raspberry PI.
6. Enable SSH on the PI: https://www.raspberrypi.org/documentation/remote-access/ssh/

On the test computer:

1. Temporarily (do not push the change) modify the script in $AFR_HOME/tests/common/framework/bleTestsScripts/runPI.sh with the IP address of your Raspberry PI:

### Test Execution

Launch the script runPI.sh and launch the test project. The tests must pass in the PI and on the DUT:

Example of tests results:

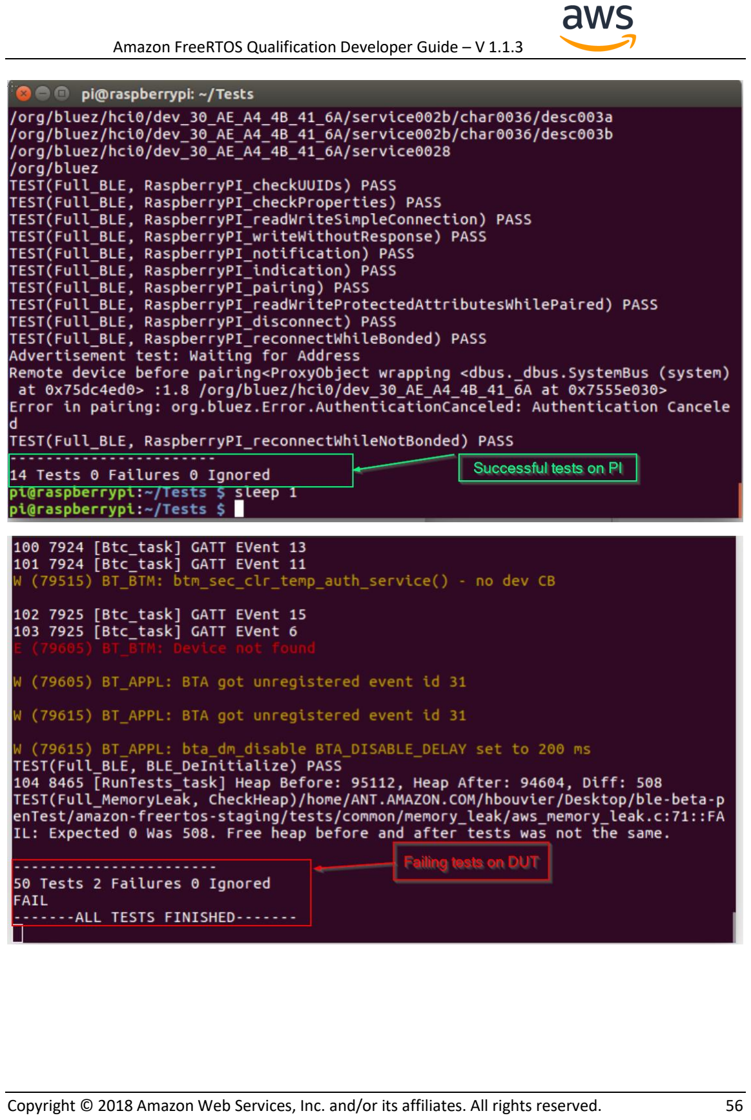
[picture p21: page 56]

Copyright © 2018 Amazon Web Services, Inc. and/or its affiliates. All rights reserved. | 56

Copyright © 2018 Amazon Web Services, Inc. and/or its affiliates. All rights reserved. | 57

## 5.12 Appendix L: Test List

The tests listed here are the current tests we provide. It is subject to change.

Library | Tests | Notes
Wi-Fi | WiFiOnOff
WiFiMode
WiFiConnectionLoop
WiFiIsConnected
WiFiNetworkAddGetDelete
WiFiPowerManagementMode
WiFiGetIP
WiFiGetMAC
WiFiGetHostIP
WiFiScan
WiFiReset
WiFiPing
WiFiConnectMultipleAP
WiFiSeperateTasksConnectingAndDisconnectingAtOnce WiFiOnOffLoop
WIFI_GetMode_NullParameters WIFI_GetIP_NullParameters
WIFI_GetMAC_NullParameters WIFI_GetHostIP_NullParameters WIFI_Scan_NullParameters
WIFI_NetworkAdd_NullParameters WIFI_NetworkGet_NullParameters WIFI_SetPMMode_NullParameters WIFI_GetPMMode_NullParameters WIFI_Ping_NullParameters
WIFI_ConnectAP_NullParameters WIFI_SetMode_InvalidMode
WIFI_GetHostIP_InvalidDomainName WIFI_GetHostIP_DomainNameLengthExceeded WIFI_NetworkDelete_DeleteNonExistingNetwork WIFI_NetworkGetNonExistingNetwork WIFI_SetPMMode_InvalidPMMode WIFI_Ping_ZeroParameters
WIFI_ConnectAP_InvalidSSID WIFI_ConnectAP_InvalidPassword WIFI_ConnectAP_InvalidSecurityTypes WIFI_ConnectAP_MaxSSIDLengthExceeded WIFI_ConnectAP_MaxPasswordLengthExceeded WIFI_ConnectAP_ZeroLengthSSID WIFI_ConnectAP_ZeroLengthPassword WIFI_ConnectAP_PasswordLengthLess

Copyright © 2018 Amazon Web Services, Inc. and/or its affiliates. All rights reserved. | 58
Library | Tests | Notes
| WIFI_Scan_ZeroScanNumber
WIFI_NetworkGet_GetManyNetworks WIFI_NetworkAdd_AddManyNetworks WIFI_NetworkDelete_DeleteManyNetworks WIFI_ConnectAP_ConnectAllChannels
| SOCKETS_Threadsafe_SameSocketDifferentTasks
| SOCKETS_Threadsafe_DifferentSocketsDifferentTasks
| SOCKETS_Connect_InvalidAddressLength
| SOCKETS_Connect_InvalidParams
| SOCKETS_Socket_TCP
| SOCKETS_SetSockOpt_RCVTIMEO
| SOCKETS_SetSockOpt_InvalidParams
| SOCKETS_Shutdown
| SOCKETS_ShutdownInvalidParams
| SOCKETS_ShutdownWithoutReceiving
| SOCKETS_Close
| SOCKETS_CloseInvalidParams
| SOCKETS_CloseWithoutReceiving
| SOCKETS_Recv_ByteByByte
| SOCKETS_Recv_On_Unconnected_socket
| SOCKETS_SendRecv_VaryLength
| SOCKETS_Socket_InvalidTooManySockets
| SOCKETS_Socket_InvalidInputParams
| SOCKETS_Send_Invalid
| SOCKETS_Recv_Invalid
| SOCKETS_htos_HappyCase
| SOCKETS_inet_addr_quick_HappyCase
| SOCKETS_NonBlocking_Test
| SECURE_SOCKETS_Threadsafe_DifferentSocketsDifferentTasks
| SECURE_SOCKETS_Threadsafe_SameSocketDifferentTasks
| SECURE_SOCKETS_Connect_InvalidAddressLength
| SECURE_SOCKETS_Connect_InvalidParams
| SECURE_SOCKETS_NonBlockingConnect
| SECURE_SOCKETS_NonBlocking_Test
| SECURE_SOCKETS_SetSockOpt_SERVER_NAME_INDICATION
| SECURE_SOCKETS_SetSockOpt_TRUSTED_SERVER_CERTIFICATE
| SECURE_SOCKETS_SetSockOpt_RCVTIMEO
| SECURE_SOCKETS_SetSockOpt_InvalidParams
| SECURE_SOCKETS_Shutdown
| SECURE_SOCKETS_ShutdownInvalidParams
| SECURE_SOCKETS_ShutdownWithoutReceiving
| SECURE_SOCKETS_Close
| SECURE_SOCKETS_CloseInvalidParams
| SECURE_SOCKETS_CloseWithoutReceiving

Secure
Sockets

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

Copyright © 2018 Amazon Web Services, Inc. and/or its affiliates. All rights reserved. | 60
Library | Tests | Notes
| MQTT_Init_NULLParams
MQTT_Connect_HappyCase
MQTT_Connect_BrokerRejectsConnection MQTT_Connect_ConnACKWithoutConnect MQTT_Connect_ReservedReturnCodeFromBroker MQTT_Connect_ShorterConnACK MQTT_Connect_LongerConnACK MQTT_Connect_NULLParams
MQTT_Connect_SecondConnectWhileAlreadyConnected MQTT_Connect_SecondConnectWhileWaitingForConnACK MQTT_Connect_NetworkSendFailed prvGetTopicFilterType_HappyCases prvGetTopicFilterType_ErrorCases prvDoesTopicMatchTopicFilter_MatchCases prvDoesTopicMatchTopicFilter_NotMatchCases
OTA | OTA_SetImageState_InvalidParams
prvParseJobDocFromJSONandPrvOTA_Close prvParseJSONbyModel_Errors prvPAL_CloseFile_ValidSignature prvPAL_CloseFile_InvalidSignatureBlockWritten prvPAL_CloseFile_InvalidSignatureNoBlockWritten prvPAL_CloseFile_NonexistingCodeSignerCertificate prvPAL_CreateFileForRx_CreateAnyFile prvPAL_Abort_OpenFile
prvPAL_Abort_FileWithBlockWritten prvPAL_Abort_NullFileHandle prvPAL_Abort_NonExistentFile prvPAL_WriteBlock_WriteSingleByte prvPAL_WriteBlock_WriteManyBlocks prvPAL_SetPlatformImageState_SelfTestImageState prvPAL_SetPlatformImageState_InvalidImageState prvPAL_SetPlatformImageState_UnknownImageState prvPAL_SetPlatformImageState_RejectImageState prvPAL_GetPlatformImageState_InvalidImageStateFromFileCloseFai lure

prvPAL_ReadAndAssumeCertificate_ExistingFile prvPAL_CheckFileSignature_ValidSignature prvPAL_CheckFileSignature_InvalidSignatureBlockWritten prvPAL_CheckFileSignature_InvalidSignatureNoBlockWritten prvPAL_CheckFileSignature_NonexistingCodeSignerCertificate OtaTestGreaterVersion
OtaTestUnsignedImage
OtaTestSameVersion
OtaTestUntrustedCertificate

Copyright © 2018 Amazon Web Services, Inc. and/or its affiliates. All rights reserved. | 61
Library | Tests | Notes
| OtaTestCorruptImageBeforeSigning
OtaTestPreviousVersion
OtaTestCorruptImageAfterSigning OtaTestCorruptSignature
OtaTestSingleByteImage
OtaTestMissingFilename
OtaTestIncorrectPlatform
OtaTestBackToBackDownloads OtaTestIncorrectWifiPassword
| BLE_Initialize_common_GAP
| BLE_Initialize_BLE_GAP
| BLE_Initialize_BLE_GATT
| BLE_CreateAttTable_CreateServices
| BLE_CreateAttTable_CreateCharacteristics
| BLE_CreateAttTable_Descriptors
| BLE_CreateAttTable_IncludedService | Disabled
| BLE_CreateAttTable_StartService
| BLE_Advertising_SetProperties
| BLE_Advertising_SetAvertisementData
| BLE_Advertising_StartAdvertisement
| BLE_Connection_SimpleConnection
| BLE_Connection_UpdateConnectionParamReq
| BLE_Property_WriteCharacteristic
| BLE_Property_WriteDescriptor
| BLE_Property_ReadCharacteristic
| BLE_Property_ReadDescriptor
| BLE_Property_WriteNoResponse
| BLE_Property_Notification
| BLE_Property_Indication
| BLE_Connection_Mode1Level4
| BLE_Connection_Mode1Level4_Property_WriteDescr
| BLE_Connection_Mode1Level4_Property_WriteChar
| BLE_Connection_Disconnect
| BLE_Connection_BondedReconnectAndPair
| BLE_Connection_Disconnect
| BLE_Connection_CheckBonding
| BLE_Connection_RemoveBonding
| BLE_Connection_Mode1Level2
| BLE_DeInitialize
BLE (test on PI) | advertisement
| discoverPrimaryServices
| simpleConnection
| checkProperties
| checkUUIDs

BLE
(test on DUT)

Copyright © 2018 Amazon Web Services, Inc. and/or its affiliates. All rights reserved. | 62
Library | Tests | Notes
| readWriteSimpleConnection
writeWithoutResponse
notification
indication
readWriteProtectedAttributesWhileNotPaired readWriteProtectedAttributesWhilePaired pairing
disconnect
reconnectWhileBonded
reconnectWhileNotBonded
Total | 215

Copyright © 2018 Amazon Web Services, Inc. and/or its affiliates. All rights reserved. | 63

## 5.13 Appendix M: TLS Server Setup

A simple TLS echo server is provided with Amazon FreeRTOS code. It is located in $AFR_HOME/tools/echo_server/tls_echo_server.go.

Instructions:

1. Install the latest version of GO on your server host: https://golang.org/dl/
2. Install openssl on your server host:
a. Linux --- https://www.openssl.org/source/
b. Windows --- https://slproweb.com/products/Win32OpenSSL.html
3. Copy tls_echo_server.go to a directory you choose.
4. Generate a TLS server self-signed certificate and private key. See $AFR_HOME/tools/echo_server/readme-gencert.txt for the openssl commands to generate a self-signed server certificate and private key.
5. Copy the certificate and private key .pem files into a subdirectory called “certs”. The “certs” directory should be a subdirectory of the directory where the server code will run.
6. Start the TLS server by running: go run tls_echo_server.go
7. The server will listen on port 9000. The IP address and the port must be set in $AFR_HOME/tests/common/include/aws_test_tcp.h. For example if your server’s IP address is 192.168.2.6, set the following macros:
Macro definition for TLS server | Example value if address is 192.168.0.200
tcptestECHO_SERVER_TLS_ADDR0 | 192
tcptestECHO_SERVER_TLS_ADDR1 | 168
tcptestECHO_SERVER_TLS_ADDR2 | 2
tcptestECHO_SERVER_TLS_ADDR3 | 6
tcptestECHO_PORT_TLS | ( 9000 )
8. The tests will check the server certificate. In
$AFR_HOME/tests/common/include/aws_test_tcp.h, set tcptestECHO_HOST_ROOT_CA to your formatted server certificate.
You can use the formatting tool to format your server certificate.
9. The AFQ secure sockets tests require TLS mutual authentication to be configured. The readme-gencert.txt file also describes how to generate a client certificate and private key that is signed by the server key. This will allow the custom echo server to trust the client certificate presented by your device during TLS authentication. The client certificate and private key must be PEM formatted and copied into aws_clientcredential_keys.h before building and running the test project on the device.

Copyright © 2018 Amazon Web Services, Inc. and/or its affiliates. All rights reserved. | 64

## 5.14 Appendix N: “Hello World” Demo Project Set Up

### Amazon FreeRTOS Directory Structure

All qualified Amazon FreeRTOS ports use the same directory structure, so all new files, including IDE project files, must be created in the correct folder locations. The directory structure is explained below.

The three root level folders under $AFR_HOME are:

$AFR_HOME
├───demos | Contains projects that build demo applications
├───lib | Contains Amazon FreeRTOS and third-party libraries
└───tests | Contains projects that build qualification tests

Your project is to be created within the demos folder, which is structured as follows:

$AFR_HOME
└───demos
├───common | Contains files built by all demo projects
├───pc | Contains a demo project for the FreeRTOS Windows port
└───vendor | Contains your vendor specific code
└───board | Contains your board specific code

The $AFR_HOME/demos/[vendor]/[board] folder is a template provided to simplify the creation of a new test project and ensures all test projects have a consistent organization. It has the following structure:

$AFR_HOME
└───demos
└───[vendor]
└───[board]
├───common
│ | ├───application_code | Contains main.c
│ | │ | └───vendor_code | Contains vendor supplied board specific files
│ | └───config_files | Contains Amazon FreeRTOS config files
└───ide | Contains an IDE specific project

Your demo projects always require vendor-supplied driver libraries. Some vendor-supplied libraries, such as a header file that maps a GPIO output to an LED, are specific to the target development board. Other vendor-supplied libraries, such as the GPIO library itself, are specific to the target MCU family. Do not save vendor-supplied libraries that are specific to the MCU anywhere within either the $AFR_HOME/tests or $AFR_HOME/demos folders.

### Preparing Your Project Directories:

1. Rename the $AFR_HOME/demos/vendor folder to the name of the company that manufactures the MCU – from here on the folder is referred to as [vendor].

Copyright © 2018 Amazon Web Services, Inc. and/or its affiliates. All rights reserved. | 65
2. Rename the $AFR_HOME/demos/[vendor]/board folder to the name of the development board being qualified – from here on the folder is referred to as [board].
3. Copy your main.c and main.h in $AFR_HOME/demos/[vendor]/[board]/common/application_code folder. You can re-use the main.c in your aws_tests project.
4. Save any required vendor-supplied libraries that are specific to the board in the $AFR_HOME/demos/[vendor]/[board]/common/application_code/vendor_code folder.
5. Rename the $AFR_HOME/demos/[vendor]/[board]/ide folder to the name of the IDE that will be used to build the test project – from here on the folder is referenced as [ide].

### Create the “Hello World” Demo Project

If your IDE does not use relative paths, define a variable in the project for relative folder locations before importing Amazon FreeRTOS source files.

1. Create an IDE project aws_demos in the $AFR_HOME/demos/[vendor]/[board]/[ide] directory.
2. Create the project structure in the IDE
3. Create three top level virtual folders:
a. application_code
b. config_files
c. lib
4. Import the $AFR_HOME/demos/[vendor]/[board]/common/application_code directory and its contents into the application_code virtual folder.
5. Import the files in $AFR_HOME/demos/[vendor]/[board]/common/config_files into the config_files virtual folder.
6. Create a virtual folder under application_code and call it common_demos.
7. Create a source folder under common_demos.
8. Import the files in each of the following directories into the source folder:
a. $AFR_HOME/demos/common/demo_runner
b. $AFR_HOME/demos/common/devmode_key_provisioning (only the .c file)
c. $AFR_HOME/demos/common/mqtt
d. $AFR_HOME/demos/common/logging
9. Import the following directories and its contents into common_demos folder.
a. $AFR_HOME/demos/common/include
10. Create two virtual folders aws and third_party under virtual folder lib
11. Import each of the following directories and their contents into the aws folder:
a. $AFR_HOME/lib/bufferpool
b. $AFR_HOME/lib/FreeRTOS
c. $AFR_HOME/lib/FreeRTOS/portable/MemMang/heap_4.c
d. $AFR_HOME/lib/FreeRTOS/portable/[compiler your IDE uses]
e. $AFR_HOME/lib/FreeRTOS-Plus-TCP (if you have ported this library, please refer to Appendix D on what files should be included in this project)
f. $AFR_HOME/lib/include
g. $AFR_HOME/lib/include/private (only .h files)
h. $AFR_HOME/lib/mqtt
i. $AFR_HOME/lib/pkcs11/portable/[vendor]/[board]/pkcs11.c (under pkcs11 folder)

Copyright © 2018 Amazon Web Services, Inc. and/or its affiliates. All rights reserved. | 66

$AFR_HOME/lib/secure_sockets/portable/[vendor]/[board]/aws_secure_sockets.c (under secure_sockets folder)
j. $AFR_HOME/lib/tls (if you have ported TLS library)
k. $AFR_HOME/lib/wifi/portable/[vendor]/[board]/aws_wifi.c (under wifi folder, if you have ported WI-FI library)
12. Import each of the following directories and their contents into third_party:
a. $AFR_HOME/lib/third_party/mcu_vendor/[vendor]/[board]/[driver_library]/[dri ver_library_version] (under mcu_vendor folder)
b. $AFR_HOME/lib/third_party/mbedtls (rename ../mbedtls/library to ../mbedtls/source)
c. $AFR_HOME/lib/third_party/pkcs11
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

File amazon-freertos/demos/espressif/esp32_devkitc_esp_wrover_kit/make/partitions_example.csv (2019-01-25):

# Name | Type | SubType | Offset | Size | Flags
# Note: if you change the phy_init or app partition offset | make sure to change the offset in Kconfig.projbuild
nvs | data | nvs | 0x10000 | 0x6000
otadata | data | ota | 0x16000 | 0x2000
phy_init | data | phy | 0x18000 | 0x1000
ota_0 | 0 | ota_0 | 0x20000 | 1500K
ota_1 | 0 | ota_1 |  | 1500K
storage | data | nvs |  | 0x10000

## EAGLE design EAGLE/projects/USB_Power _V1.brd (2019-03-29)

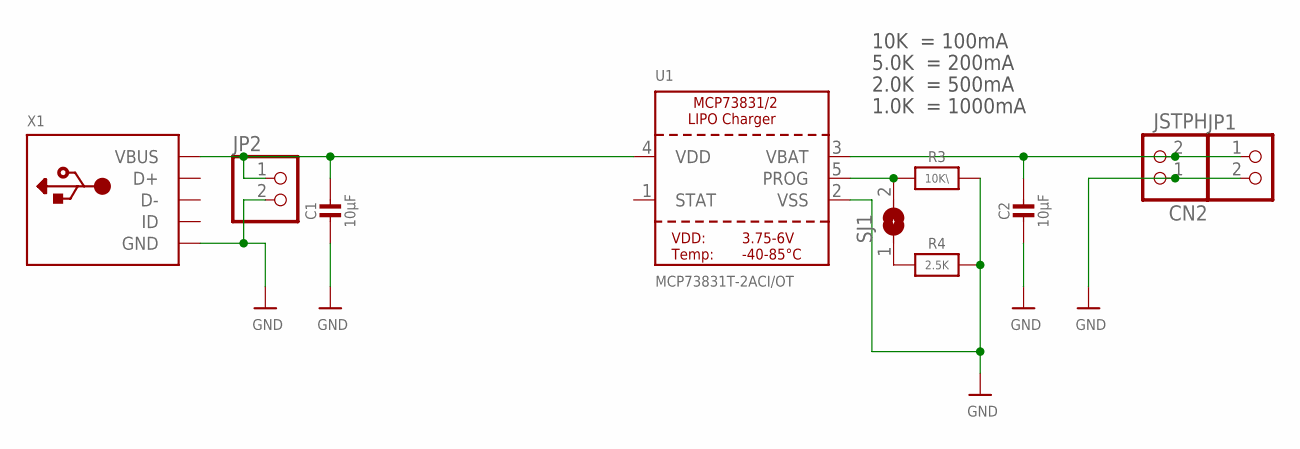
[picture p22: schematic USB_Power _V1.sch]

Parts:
C1, C2: 10µF; 0805-NO
CN2: JSTPH; JSTPH2
JP1, JP2: HEADER-1X2ROUND; 1X02_ROUND
R3: 10K\; 0805-NO
R4: 2.5K; 0805-NO
SJ1: SOLDERJUMPER; SOLDERJUMPER_ARROW_NOPASTE
U1: MCP73831T-2ACI/OT; SOT23-5
X1: USB_MEDIUM; USB-MINI_MEDIUM

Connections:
GND: C1.2, C2.2, CN2.1, JP1.2, JP2.2, R3.2, R4.2, U1.2 (VSS), X1.GND, X1.GND1 (GND), X1.GND2 (GND), X1.GND3 (GND), X1.GND4 (GND)
unnamed: R4.1, SJ1.1
unnamed: R3.1, SJ1.2, U1.5 (PROG)
VBAT: C2.1, CN2.2, JP1.1, U1.3 (VBAT)
VDD: C1.1, JP2.1, U1.4 (VDD), X1.VBUS

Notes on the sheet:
10K = 100mA
5.0K = 200mA
2.0K = 500mA
1.0K = 1000mA

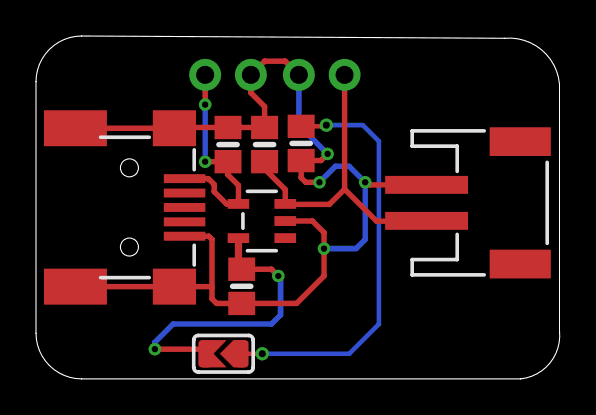
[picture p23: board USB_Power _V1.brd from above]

Board: 2 copper layers, 29.1 x 19.1 mm, 10 parts (0 on the bottom side), 5 nets.

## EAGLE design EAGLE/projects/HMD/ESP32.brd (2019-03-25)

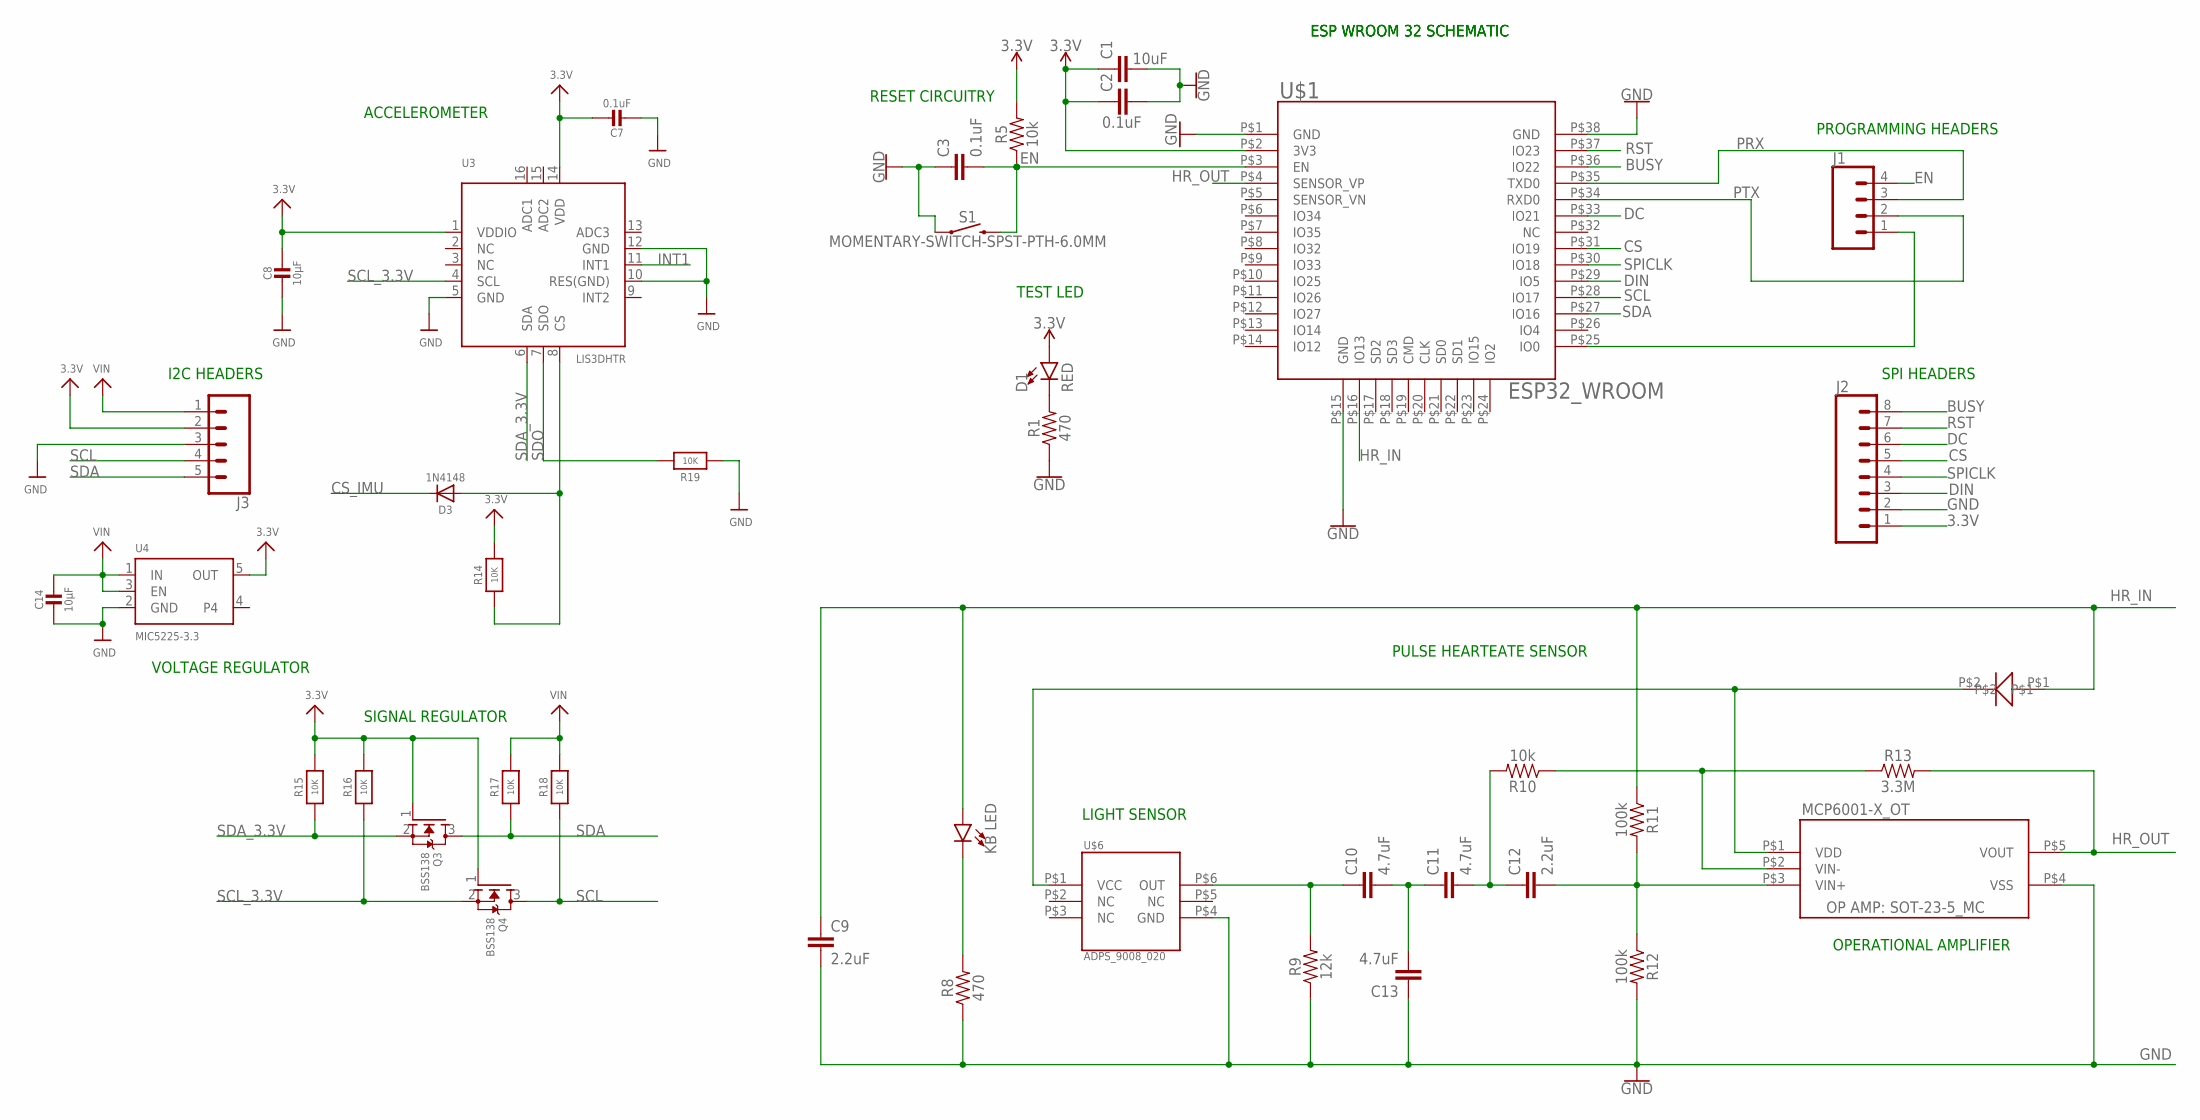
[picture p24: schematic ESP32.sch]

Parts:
C1: 10uF; 0603
C2, C3: 0.1uF; 0603
C7: 0.1uF; _0603MP
C8, C14: 10µF; _0603
C9, C12: 2.2uF; 0603
C10, C11, C13: 4.7uF; 0603
D1: RED; LED-0603
D3: 1N4148; SOD-323
J1: CONN_04; 1X04
J2: CONN_08"; 1X08
J3: CONN_05; 1X05
Q3, Q4: BSS138; SOT23-WIDE
R1, R8: 470; 0603
R5, R10: 10k; 0603
R9: 12k; 0603
R11, R12: 100k; 0603
R13: 3.3M; 0603
R14, R15, R16, R17, R18, R19: 10K; _0603
S1: MOMENTARY-SWITCH-SPST-PTH-6.0MM; TACTILE_SWITCH_PTH_6.0MM
U3: LIS3DHTR; LGA16_3X3MM
U4: MIC5225-3.3; SOT23-5
U$1: ESP32_WROOM; ESP32_FP
U$5: MCP6001-X_SOT-23-5; SOT-23-5
U$6: ADPS_9008_020; ADPS_FP
U$7: KB_REVMNT_LED; REVMNT_LED_FP
U$8: DI0603; DIODE0603

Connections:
3.3V: C1.1, C2.1, C7.1, C8.1, D1.A, J2.1, J3.2, Q3.1 (G), Q4.1 (G), R5.2, R14.2, R15.2, R16.2, U3.1 (VDDIO), U3.14 (VDD), U4.5 (OUT), U$1.P$2 (3V3)
BUSY: J2.8, U$1.P$36 (IO22)
CS: J2.5, U$1.P$31 (IO19)
CS_IMU: D3.C
DC: J2.6, U$1.P$33 (IO21)
DIN: J2.3, U$1.P$29 (IO5)
EN: C3.2, J1.4, R5.1, S1.3 (2), U$1.P$3 (EN)
GND: C1.2, C2.2, C3.1, C7.2, C8.2, C9.2, C13.1, C14.2, J2.2, J3.3, R1.1, R8.1, R9.1, R12.2, R19.1, S1.1, U3.5 (GND), U3.10 (RES(GND)), U3.12 (GND), U4.2 (GND), U$1.P$1 (GND), U$1.P$15 (GND), U$1.P$38 (GND), U$5.P$4 (VSS), U$6.P$4 (GND)
HR_IN: C9.1, R11.1, U$1.P$16 (IO13), U$7.P$1 (A), U$8.P$1
HR_OUT: R13.2, U$1.P$4 (SENSOR_VP), U$5.P$5 (VOUT)
INT1: U3.11 (INT1)
unnamed: D3.A, R14.1, U3.8 (CS)
unnamed: D1.C, R1.2
unnamed: J1.1, U$1.P$25 (IO0)
unnamed: C10.1, R9.2, U$6.P$6 (OUT)
unnamed: C10.2, C11.1, C13.2
unnamed: C11.2, C12.1, R10.2
unnamed: C12.2, R11.2, R12.1, U$5.P$3 (VIN+)
unnamed: R10.1, R13.1, U$5.P$2 (VIN-)
unnamed: U$5.P$1 (VDD), U$6.P$1 (VCC), U$8.P$2
unnamed: R8.2, U$7.P$2 (C)
PRX: J1.3, U$1.P$35 (TXD0)
PTX: J1.2, U$1.P$34 (RXD0)
RST: J2.7, U$1.P$37 (IO23)
SCL: J3.4, Q4.3 (D), R18.1, U$1.P$28 (IO17)
SCL_3.3V: Q4.2 (S), R16.1, U3.4 (SCL)
SDA: J3.5, Q3.3 (D), R17.1, U$1.P$27 (IO16)
SDA_3.3V: Q3.2 (S), R15.1, U3.6 (SDA)
SDO: R19.2, U3.7 (SDO)
SPICLK: J2.4, U$1.P$30 (IO18)
VIN: C14.1, J3.1, R17.2, R18.2, U4.1 (IN), U4.3 (EN)

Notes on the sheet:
ESP WROOM 32 SCHEMATIC
SPI HEADERS
PULSE HEARTEATE SENSOR
OPERATIONAL AMPLIFIER
LIGHT SENSOR
RESET CIRCUITRY
I2C HEADERS
PROGRAMMING HEADERS
VOLTAGE REGULATOR
ACCELEROMETER
SIGNAL REGULATOR
TEST LED

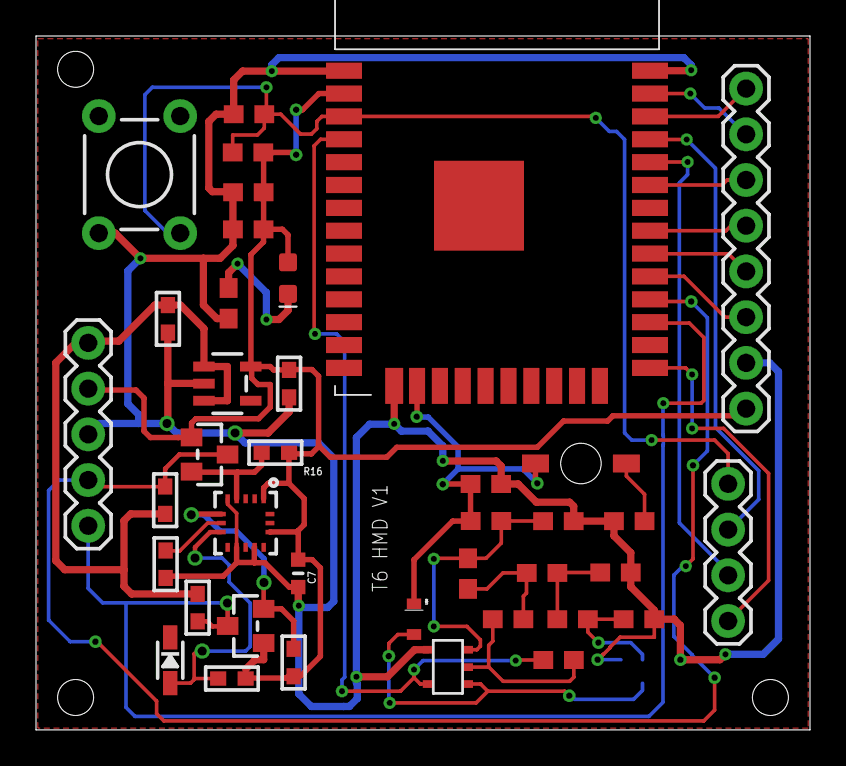
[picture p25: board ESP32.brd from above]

Board: 2 copper layers, 43.0 x 38.5 mm, 40 parts (1 on the bottom side), 29 nets.

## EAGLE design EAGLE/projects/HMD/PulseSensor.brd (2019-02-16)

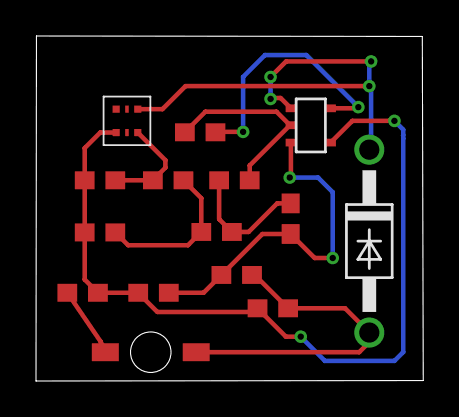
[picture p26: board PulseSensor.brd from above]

Board: 2 copper layers, 21.5 x 19.2 mm, 15 parts (0 on the bottom side), 10 nets.

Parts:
C1, C2, C3: 4.7uF; 0603
C4, C5: 2.2uF; 0603
D1: 1N4004; DO41-10
R1: 470; 0603
R2: 12k; 0603
R3, R4: 100k; 0603
R5: 10k; 0603
R6: 3.3M; 0603
U$1: ADPS_9008_020; ADPS_FP
U$2: KB_REVMNT_LED; REVMNT_LED_FP
U$3: MCP6001-X_SOT-23-5; SOT-23-5

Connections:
3.3V: C5.1, D1.A, R4.1, U$2.P$1
GND: C1.1, C5.2, R1.1, R2.1, R3.2, U$1.P$4, U$3.P$4
HR_OUT: R6.2, U$3.P$5
unnamed: C2.1, R2.2, U$1.P$6
unnamed: C1.2, C2.2, C3.1
unnamed: C3.2, C4.1, R5.2
unnamed: C4.2, R3.1, R4.2, U$3.P$3
unnamed: R1.2, U$2.P$2
unnamed: R5.1, R6.1, U$3.P$2
unnamed: D1.C, U$1.P$1, U$3.P$1

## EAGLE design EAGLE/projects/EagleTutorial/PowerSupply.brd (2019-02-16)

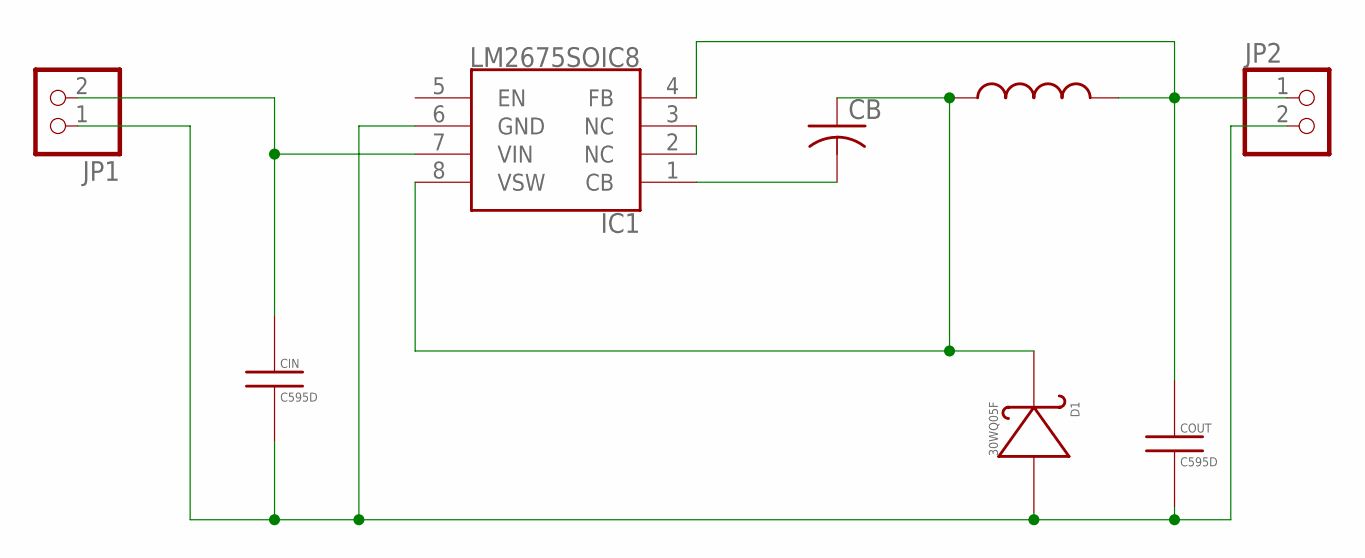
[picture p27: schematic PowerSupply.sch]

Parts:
CB: 0.01uF; C1206
CIN: C595D; C_595D
COUT: C595D; C_595D
D1: 30WQ05F; D_SMA
IC1: LM2675SOIC8; SO8
JP1, JP2: PINHD-1X2; 1X02
L: SDR1005L_SMD_V; L_SMD

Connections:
unnamed: CIN.P$2, IC1.7 (VIN), JP1.2
unnamed: CIN.P$1, COUT.P$1, D1.P$1, IC1.6 (GND), JP1.1, JP2.2
unnamed: COUT.P$2, IC1.4 (FB), JP2.1, L.P$1
unnamed: CB.1, D1.P$2, IC1.8 (VSW), L.P$2
unnamed: CB.2, IC1.1 (CB)
unnamed: IC1.2 (NC), IC1.3 (NC)

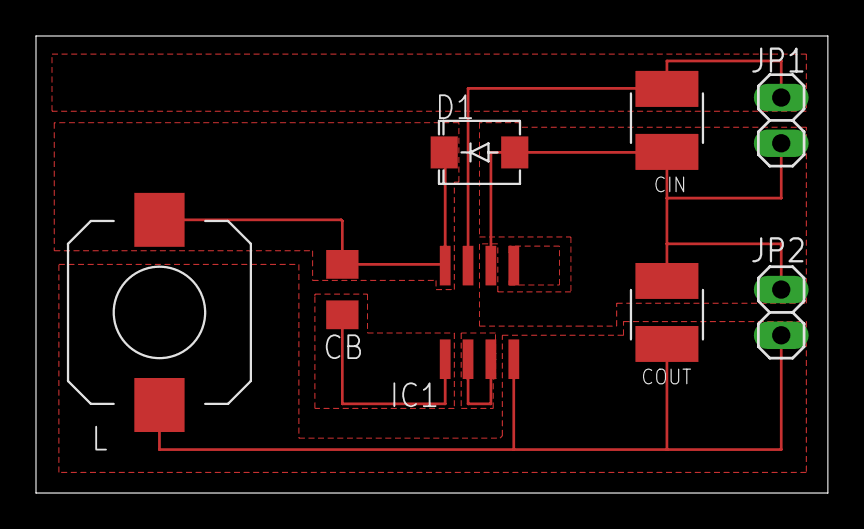
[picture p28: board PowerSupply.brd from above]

Board: 2 copper layers, 44.0 x 25.4 mm, 8 parts (0 on the bottom side), 6 nets.

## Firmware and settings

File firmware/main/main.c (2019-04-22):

#include <stdio.h>
#include <stdlib.h>
#include <string.h>
#include "freertos/FreeRTOS.h"
#include "freertos/task.h"
#include "freertos/event_groups.h"
#include "esp_system.h"
#include "esp_log.h"
#include "nvs_flash.h"
#include "esp_bt.h"

#include "esp_gap_ble_api.h"
#include "esp_gatts_api.h"
#include "esp_bt_defs.h"
#include "esp_bt_main.h"
#include "esp_bt_main.h"
#include "sdkconfig.h"
#include "features.h"
#include "driver/gpio.h"
#define TAG "HMD_MAIN"

display_data_t display_data;



void BLE_init() {
    esp_err_t ret;
    esp_bt_controller_config_t bt_cfg = BT_CONTROLLER_INIT_CONFIG_DEFAULT();

    ret = esp_bt_controller_mem_release(ESP_BT_MODE_CLASSIC_BT);
    if (ret) {
        ESP_LOGI(TAG, "Bluetooth controller release classic bt memory failed: %s", esp_err_to_name(ret));
        return;
    }

    ret = esp_bt_controller_init(&bt_cfg);
    if (ret) {
        ESP_LOGE(TAG, "%s initialize controller failed\n", __func__);
        return;
    }

    ret = esp_bt_controller_enable(ESP_BT_MODE_BLE);
    if (ret) {
        ESP_LOGE(TAG, "%s enable controller failed\n", __func__);
        return;
    }
    ret = esp_bluedroid_init();
    if (ret) {
        ESP_LOGE(TAG, "%s init bluetooth failed\n", __func__);
        return;
    }
    ret = esp_bluedroid_enable();
    if (ret) {
        ESP_LOGE(TAG, "%s enable bluetooth failed\n", __func__);
        return;
    }
}


void app_main() {

    esp_err_t ret = nvs_flash_init();
	if (ret == ESP_ERR_NVS_NO_FREE_PAGES || ret == ESP_ERR_NVS_NEW_VERSION_FOUND) {
		ESP_ERROR_CHECK(nvs_flash_erase());
		ret = nvs_flash_init();
	}
	ESP_ERROR_CHECK( ret );

    //display_data_t * display_data = (display_data_t * )calloc(1, sizeof(display_data_t));

    memset(&display_data, 0x00, sizeof(display_data));
    display_data.current_mode = PAIRING_MODE;


    // // initializations ***************************************************** make sure you initiazile!!@@@@@@@@@
    BLE_init();
    IMU_init();
    heartRate_ADC_init();
    gpio_pad_select_gpio(GPIO_NUM_13);
    gpio_set_direction(GPIO_NUM_13, GPIO_MODE_OUTPUT);
    gpio_set_level(GPIO_NUM_13, 0);

    // // msg received callbacks
    esp_ble_gatts_register_callback(gatts_event_handler);
    esp_ble_gap_register_callback(gap_event_handler);
    esp_ble_gatts_app_register(BLE_PROFILE_APP_ID);


    // Main tasks
    
    
    //xTaskCreate(&IMU_task, "IMU_task", 4 * 1024, NULL, 5, NULL);
    xTaskCreate(&BPM_task, "BPM_task", 4096, NULL, 5, NULL);
    
    /* Task used to test the epaper display*/
    //xTaskCreate(&e_paper_task, "e_paper_task", 4 * 1024, &display_data, 5, NULL);

    //xTaskCreate(&ActivityMode_task, "ActivityMode_task", 4 * 1024, NULL, 5, NULL);
    //xTaskCreate(&SleepMode_task, "SleepMode_task", 4 * 1024, &display_data, 5, NULL);

    /* Testing tasks */
    //xTaskCreate(&blink_task, "blink_task", configMINIMAL_STACK_SIZE, NULL, 5, NULL);
    //gpio_set_level(GPIO_NUM_13,1);

}

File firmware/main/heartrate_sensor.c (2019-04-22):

#include "freertos/FreeRTOS.h"

// Heart Rate sensor
#include <driver/adc.h>
#include "freertos/timers.h"
#include "features.h"

// fixes watchdog timer issue
#include "soc/timer_group_struct.h"
#include "soc/timer_group_reg.h"

#define BUFFER_LENGTH 10


void BPMTimerCallback( TimerHandle_t xTimer ){
    uint32_t expiredCount;
    /* The number of times this timer has expired is saved as the timer's ID. Obtain the count. */
    expiredCount = ( uint32_t ) pvTimerGetTimerID( xTimer );
    /* Increment the count, and then test to see if the timer has expired maxExpiredCount yet. */
    expiredCount++;
    vTimerSetTimerID( xTimer, ( void * ) expiredCount );
}

void heartRate_ADC_init() {
    /* Initialize and start the heart rate adc */
    adc1_config_width(ADC_WIDTH_BIT_12);
    adc1_config_channel_atten(ADC1_CHANNEL_0,ADC_ATTEN_DB_11);
}


TimerHandle_t heartRate_timer_init() {
    /* Create timer to count for BPM*/
    TimerHandle_t bpm_timer;
    bpm_timer = xTimerCreate( "Timer", pdMS_TO_TICKS( 10 ), pdTRUE, ( void * ) 0, BPMTimerCallback );
    if( bpm_timer == NULL ){
        /* The timer was not created. */
    }
    else{
            /* Start the timer. No block time is specified. Even if one were specified, it would be ignored because the RTOS scheduler has not yet been started. */
            if( xTimerStart( bpm_timer, 0 ) != pdPASS ){
                /* The timer could not be set into the Active state. */
            }
    }

    return bpm_timer;
}


int heartRate_collect_data(int *down_count, int *up_count, uint32_t *expiredCountBuffer, uint8_t *bufferWriteIndex, TimerHandle_t *bpm_timer) {
    int bpm = 0;
    int hrt_bt_adc_val = 0;    
    int expiredCount = 0;
    
    /* fixes watchdog timer issue */
    TIMERG0.wdt_wprotect=TIMG_WDT_WKEY_VALUE;
    TIMERG0.wdt_feed=1;
    TIMERG0.wdt_wprotect=0;

    /* The value from the adc for Heart Beat sensor */
    hrt_bt_adc_val = adc1_get_raw(ADC1_CHANNEL_0);
    // printf("down_count: %d\n", *down_count);
    // printf("up_count: %d\n", *up_count);
    printf("hrt_bt_adc_val: %d\n", hrt_bt_adc_val);

    /* Thresholds to calculate the if there was a heart beat or not */
    if( hrt_bt_adc_val < 1683){
        *down_count = *down_count + 1;
    }
    if(*down_count > 10 && hrt_bt_adc_val > 1882){
        *up_count = *up_count + 1;
    }
    if( *up_count > 20 && hrt_bt_adc_val < 1753){
        
        *down_count = 0;
        *up_count = 0;
        
        /* The number of times this timer has expired is saved as the timer's ID. Obtain the count. */
        expiredCount = ( uint32_t ) pvTimerGetTimerID(*bpm_timer);
        /* Write new expiredCount to buffer */
        expiredCountBuffer[ *bufferWriteIndex ] = expiredCount;
        *bufferWriteIndex = *bufferWriteIndex + 1;
        if (*bufferWriteIndex == BUFFER_LENGTH){
            *bufferWriteIndex = 0;
        }

        /* Average expire count in buffer */
        for(uint8_t index = 0; index <BUFFER_LENGTH; index++){
            expiredCount += expiredCountBuffer[ index ];
        }
        expiredCount = expiredCount / BUFFER_LENGTH;
        
        /* Expires every 1/100 of a second. Calc BPM*/
        bpm =  (100 * 60 * 1) / expiredCount;

        //configPRINTF( ( "BEAT! ADC Val: %d  BPM: %d \r\n", hrt_bt_adc_val, bpm ) );
        //printf("BEAT! ADC Val: %d  BPM: %d \r\n", hrt_bt_adc_val, bpm);
        printf("BEAT! ADC Val: %d  BPM: %d\n", hrt_bt_adc_val, bpm);
        /* Reset timer */
        xTimerReset(*bpm_timer, 0);
        vTimerSetTimerID(*bpm_timer, 0);

        return bpm;
    }
    
    return -1;
}



void BPM_task(void *pvParameter) {
    /* Create timer to count for BPM*/
    TimerHandle_t bmp_timer;
    bmp_timer = xTimerCreate( "Timer", pdMS_TO_TICKS( 10 ), pdTRUE, ( void * ) 0, BPMTimerCallback );
    if( bmp_timer == NULL ){
        /* The timer was not created. */
    }
    else{
        /* Start the timer. No block time is specified. Even if one were specified, it would be ignored because the RTOS scheduler has not yet been started. */
        if( xTimerStart( bmp_timer, 0 ) != pdPASS ){
            /* The timer could not be set into the Active state. */
        }
    }

    /* Initialize and start the heart rate adc */
    adc1_config_width(ADC_WIDTH_BIT_12);
    adc1_config_channel_atten(ADC1_CHANNEL_0,ADC_ATTEN_DB_11);

    int down_count = 0;
    int up_count = 0;
    int hrt_bt_adc_val = 0;
    int expiredCount = 0;
    #define BUFFER_LENGTH 15
    #define FILTER_AMOUNT 15
    int rawLPFilter[ FILTER_AMOUNT ];
    int lpFilterWriteIndex = 0;
    int expiredCountBuffer[ BUFFER_LENGTH ];
    int bufferWriteIndex = 0;
    int bpm = 0;
    while (1) {

        
        /* fixes watchdog timer issue */
        TIMERG0.wdt_wprotect=TIMG_WDT_WKEY_VALUE;
        TIMERG0.wdt_feed=1;
        TIMERG0.wdt_wprotect=0;

        /* The value from the adc for Heart Beat sensor */
        hrt_bt_adc_val = adc1_get_raw(ADC1_CHANNEL_0);

        /* Average Raw values to software LP filter */
        rawLPFilter[ lpFilterWriteIndex++ ] = hrt_bt_adc_val;
        if (lpFilterWriteIndex == FILTER_AMOUNT){
            lpFilterWriteIndex = 0;
        }
        /* Average raw in buffer */
        for(uint8_t index = 0; index < FILTER_AMOUNT; index++){
            hrt_bt_adc_val += rawLPFilter[ index ];
        }
        hrt_bt_adc_val = hrt_bt_adc_val / FILTER_AMOUNT;

        /* Thresholds to calculate the if there was a heart beat or not */
        if( hrt_bt_adc_val < 1683){
            down_count++;
        }
        if(down_count > 2 && hrt_bt_adc_val > 1882){
            up_count++;
        }
        if( up_count > 4 && hrt_bt_adc_val < 1753){
            
            down_count = 0;
            up_count = 0;
            
            /* The number of times this timer has expired is saved as the timer's ID. Obtain the count. */
            expiredCount = ( uint32_t ) pvTimerGetTimerID(bmp_timer);
            /* Write new expiredCount to buffer */
            expiredCountBuffer[ bufferWriteIndex ] = expiredCount;
            bufferWriteIndex ++;
            if (bufferWriteIndex == BUFFER_LENGTH){
                bufferWriteIndex = 0;
            }
            /* Average expire count in buffer */
            for(uint8_t index = 0; index <BUFFER_LENGTH;index ++){
                expiredCount += expiredCountBuffer[ index ];
            }
            expiredCount = expiredCount / BUFFER_LENGTH;
            /* Expires every 1/100 of a second. Calc BPM*/
            bpm =  (100 * 60 * 1) / expiredCount;
            display_data.hr_bpm_data = bpm;
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

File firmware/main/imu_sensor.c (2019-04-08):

#include <driver/i2c.h>
#include <esp_log.h>
#include <freertos/task.h>
#include <math.h>
#include "lis3dh.h"

// typedef struct {

//     float ax;   // acceleration on x axis
//     float ay;   // acceleration on y axis
//     float az;   // acceleration on z axis

// } lis3dh_float_data_t;

// typedef lis3dh_float_data_t lis3dh_float_data_fifo_t[32];

// I2C interface defintions for ESP32 and ESP8266
#define I2C_BUS       0
#define I2C_SCL_PIN   17
#define I2C_SDA_PIN   16
#define I2C_FREQ      I2C_FREQ_100K

#include "features.h"
#include <string.h>


/* -- user tasks --------------------------------------------------- */

static lis3dh_sensor_t* sensor;

/**
 * Common function used to get sensor data.
 */
void read_data ()
{
    lis3dh_float_data_t  data;

    if (lis3dh_new_data (sensor) &&
        lis3dh_get_float_data (sensor, &data))
        // max. full scale is +-16 g and best resolution is 1 mg, i.e. 5 digits
        //printf("LIS3DH (xyz)[g] ax=%+7.3f ay=%+7.3f az=%+7.3f\n", data.ax, data.ay, data.az);
        display_data.imu_data.ax = data.ax;
        display_data.imu_data.ay = data.ay;
        display_data.imu_data.az = data.az;
}


/*
 * In this example, user task fetches the sensor values every seconds.
 */

void IMU_task(void *pvParameters)
{
    vTaskDelay (100/portTICK_PERIOD_MS);
    
    while (1)
    {
        // read sensor data
        read_data();
        
        // passive waiting until 1 second is over
        vTaskDelay(pdMS_TO_TICKS( 500 ));
    }
}

/* -- main program ------------------------------------------------- */

void IMU_init() {
	i2c_config_t conf;
    conf.mode = I2C_MODE_MASTER;
    conf.sda_io_num = I2C_SDA_PIN;
    conf.scl_io_num = I2C_SCL_PIN;
    conf.sda_pullup_en = GPIO_PULLUP_ENABLE;
    conf.scl_pullup_en = GPIO_PULLUP_ENABLE;
    conf.master.clk_speed = I2C_FREQ;
    ESP_ERROR_CHECK(i2c_param_config(I2C_BUS, &conf));
    ESP_ERROR_CHECK(i2c_driver_install(I2C_BUS, I2C_MODE_MASTER, 0, 0, 0));

    sensor = lis3dh_init_sensor (I2C_BUS, LIS3DH_I2C_ADDRESS_1, 0);

    if (sensor)
    {
        
        /** -- SENSOR CONFIGURATION PART --- */

        // configure HPF and reset the reference by dummy read
        lis3dh_config_hpf (sensor, lis3dh_hpf_normal, 0, true, true, true, true);
        lis3dh_get_hpf_ref (sensor);
        
        // LAST STEP: Finally set scale and mode to start measurements
        lis3dh_set_scale(sensor, lis3dh_scale_2_g);
        lis3dh_set_mode (sensor, lis3dh_odr_10, lis3dh_high_res, true, true, true);

        /** -- TASK CREATION PART --- */

        // must be done last to avoid concurrency situations with the sensor
        // configuration part
    }
    else {
        printf("Could not initialize LIS3DH sensor\n");
    }
}



// void user_init(void)
// {

//     /** -- MANDATORY PART -- */

//     // init all I2C bus interfaces at which LIS3DH  sensors are connected
//     i2c_init (I2C_BUS, I2C_SCL_PIN, I2C_SDA_PIN, I2C_FREQ);
    
//     // init the sensor with slave address LIS3DH_I2C_ADDRESS_1 connected to I2C_BUS.
//     sensor = lis3dh_init_sensor (I2C_BUS, LIS3DH_I2C_ADDRESS_1, 0);
    
//     if (sensor)
//     {
        
//         /** -- SENSOR CONFIGURATION PART --- */

//         // configure HPF and reset the reference by dummy read
//         lis3dh_config_hpf (sensor, lis3dh_hpf_normal, 0, true, true, true, true);
//         lis3dh_get_hpf_ref (sensor);
        
//         // LAST STEP: Finally set scale and mode to start measurements
//         lis3dh_set_scale(sensor, lis3dh_scale_2_g);
//         lis3dh_set_mode (sensor, lis3dh_odr_10, lis3dh_high_res, true, true, true);

//         /** -- TASK CREATION PART --- */

//         // must be done last to avoid concurrency situations with the sensor
//         // configuration part

//         // create a user task that fetches data from sensor periodically
//         xTaskCreate(IMU_task, "IMU_task", 4096, NULL, 2, NULL);
//     }
//     else
//         printf("Could not initialize LIS3DH sensor\n");
// }

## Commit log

2019-01-23 initial proj setup, blink LED
2019-01-25 added awsdemo for esp32
    [esp-wroom-32.cfg, esp32.cfg, esp32_devkitj_v1.cfg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]
2019-01-26 file structure for rtos
    [esp-wroom-32.cfg, esp32.cfg, esp32_devkitj_v1.cfg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]
2019-01-27 reconfigure dir
    [STM32L475VG.cfg, aws_demos Debug.cfg, aws_tests Debug.cfg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]
2019-01-27 fresh project
    [esp-wroom-32.cfg, esp32.cfg, esp32_devkitj_v1.cfg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]
2019-02-01 added more tests
    [STM32L475VG.cfg, aws_demos Debug.cfg, r_bsp_config_readme.txt]
2019-02-02 Added basic ADC to main.c
2019-02-08 restructed for ble
    [B-L475E-IOT01A-Test Debug.cfg, STM32L475VG.cfg, aws_tests Debug.cfg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]
2019-02-14 Heart Rate & ESP32 footprints
    [PowerSupply.brd, PowerSupply.sch, PulseSensor.sch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]
2019-02-15 working mpu sensor in C
2019-02-16 Layout for PulseSensor & Schematic for ESP32
    [ESP32.sch, PulseSensor.brd]
2019-02-20 Made SPI initialization in esp-epaper-29-ws.c Changed library, need to update components/epaper-29-ws/epaper-29-ws.c and components/epaper-29-ws/epaper-29-ws.h
2019-02-23 Add files via upload
    IMU Design Block
2019-02-24 added temp files
    [Adafruit MicroUSB Lipo.brd, Adafruit MicroUSB Lipo.sch]
2019-02-24 PCB layed out
    [ESP32.brd, ESP32.sch]
2019-02-28 ble: mcu to app working for heartrate
    [Adafruit MicroUSB Lipo.brd, Adafruit MicroUSB Lipo.sch, ESP32.brd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]
2019-03-01 working mpu on app. need to figure out display management for tasks. Recalling MPU display causes crash
    [ble_server.c, main.c, mpu_sensor.c]
2019-03-01 working ble for app, samples sensor data every 30 secs
2019-03-20 Version 1 micro
    [Adafruit MicroUSB Lipo.brd, Adafruit MicroUSB Lipo.sch, ESP32.brd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]
2019-03-20 Revert "stuff"
    This reverts commit c9592abd68b907ec920e2058757725e4ef075ec8.
    [ble_server.c, mpu_sensor.c]
2019-03-20 Revert "Version 1 micro"
    This reverts commit 22c8d65d876e5e97d8f3c243cdc0f8aa191d734f.
    [Adafruit MicroUSB Lipo.brd, Adafruit MicroUSB Lipo.sch, ESP32.brd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]
2019-03-20 Final Version 1 PCB
    [ESP32.brd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]
2019-03-25 adding app and backend updates
    [ESP32.brd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]
2019-03-29 working LIS3dh code, cloud updates
    [USB_Power _V1.brd, USB_Power _V1.csv, USB_Power _V1.sch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]
2019-03-29 updated IMU code, currently working
2019-04-01 added UI template, working on integrating with current functionality
2019-04-17 sleepquality lambda fnx done, base usage case done

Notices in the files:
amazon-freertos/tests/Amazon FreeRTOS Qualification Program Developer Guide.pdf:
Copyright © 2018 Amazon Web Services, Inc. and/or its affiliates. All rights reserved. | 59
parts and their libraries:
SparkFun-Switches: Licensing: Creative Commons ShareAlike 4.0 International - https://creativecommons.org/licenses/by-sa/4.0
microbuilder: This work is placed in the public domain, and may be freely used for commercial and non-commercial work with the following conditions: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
